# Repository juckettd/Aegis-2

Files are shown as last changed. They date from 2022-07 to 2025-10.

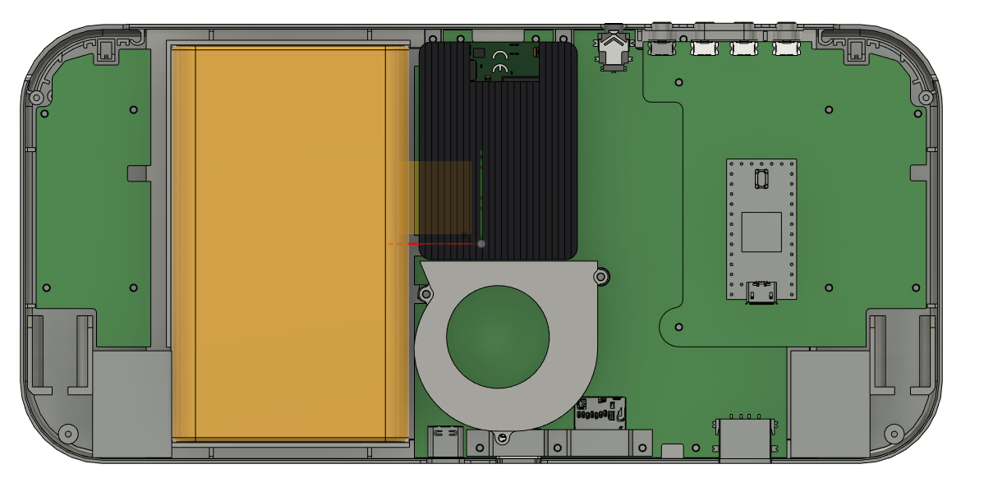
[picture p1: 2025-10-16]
Images/Aegis2_5.PNG

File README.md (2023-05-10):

# Aegis-2
The Aegis 2 Handheld with a 7" screen

NOTE: This is still a work in progress.

## Summary

The Aegis 2 is a DIY handheld that uses a 3D printed case with a Raspberry Pi CM4 and 1920x1200 7" screen.

## Building the Handheld

To build the handheld you will need the items listed as required in the Bill of Materials along with the following tools:

Reflow Station or Reflow Oven<br/>
Solding Iron<br/>
Solder Paste<br/>
Tweezers<br/>
Small Philips Screw Driver<br/>
Small Flathead Screw Driver<br/>
Super Glue (preferrably CA glue with Accelerator)

There are items in the Bill of Materials that are listed as optional. These items are not required to get a working device but can be used if desired. At this time I will not provide directions on how to use the optional components so use at your discretion.

### Assembling the Circuit Board

The custom circuit boards are provided as fusion 360 files in this repository. This includes the schematic, board layout, and the gerber files. 

To get the boards printed, a manufacturing facility is required. The website jlcpcb.com was used to print the 3 circuit board prototypes for the design. The larger of the two boards uses 4 layers, and the smaller ones use only 2 layers. It is recommended to also get the stencils with the boards so that applying the solder paste becomes much easier.

Once the boards have been received you will need to assemble the circuitry on the boards. This is done by getting all of the components provided in the bill of materials. Each item has a provided Link to where the item can be acquired along with the price at the time of the assembly of the prototype. After acquiring all of the components, use the stencil to apply solder paste to the circuit boards and then use tweezers to place each component. A reflow oven or reflow station should then be used to melt the solder paste and adhere the components. Lastly, any through hole components were then added on the using a soldering iron. 

Note: The teensy that is soldered to the board using the through holes. However, there are 4 pads that are located near the USB connector of the Teensy on the custom circuit board. They are the VBUS, D+, D-, and GND connections. I included the VBUS and GND connections as backups but they are not needed as the power and ground comes from the pins. But the D+, D- connections need to be connected to the teensy. On the underside of the teensy there are 4 pads that are in about the same location, a wire or some other form of connection is needed to connect the D+ from the teensy to the D+ on the custom circuit board, do the same with the D- connection.

While anyone who has experience with circuit boards will have their own method for assembling these boards I used the following steps and it is what I recommend for anyone without experience and a reflow oven (but a reflow station is required):
1. Using the stencil, put solder paste on the larger of the two boards on the side with a majority of the components
2. Place all of the surface mount components on that side of the board
3. Use a reflow station and heat the underside of the board until the solder paste on the top side melts to adhere the components. A tool to prop up the PCB comes in handy here. In my opinion this part is essential as some of the components are plastic and the hot air coming out of a reflow station can melt them.
4. Use a soldering iron to clean up an connections that didn't connect completely (You can watch youtube videos on how to do this, just search for solding iron and surface mount components)
5. Flip the board over and redo steps 1-4 for the underside of the board. Since these components are larger I just used the a soldering iron for all of the components, but the same procedure with the reflow station can be used. Just be careful with the hot air hitting components you have already put down, as they can fall off if the solder paste melts again.
6. Perform 1-5 for the second board and the few surface mount components that are on that board
7. Add all of the through hole items to both boards with a soldering iron (again youtube is your friend)

### Install Teensy Code

Before (or after) the circuit board has been assembled the teensy code needs to be pushed to the teensy. The teensy code is provided in the repo and you will need to follow the instructions on the teensy website for pushing code. Make sure that you set the board type to "XInput" otherwise it won't be seen as a XBox 360 Controller.

### 3D Printed Case

The files provided here for the case. They are printed in sections so that a printer with a standard bed size of 220mm x 220mm can be used print the case. Once they are printed they will have to be cleaned up and then glued together. Depending on which angle you choose to print the parts the cleanup step could be more or less cumbersome for the remove of support and getting good glue joints. I choose to print everything with flat surfaces on the bed to keep the post processing steps as easy as possible.

Once everything is glued together then no post processing on the outside is technically required to assemble the device. However, I chose to use filler, sand paper, and paint to get a really clean looking finish. The level of detail you desire on your handheld will be up to you based on how much effort you want to devote. Refer to youtube for how to sand and paint a 3D printed piece. However, try to keep the inside of the device as paint free as possible as the internal structure is already at the correct dimensions for the internal components.

I would also sand down the holes where the buttons will be located as they will to be rough from the 3D printing process. This can cause the buttons to stick. I would also check the shoulder buttons to make sure there is not any friction preventing them from moving properly. If there is then sand down the appropriate areas.

### Assembly

Once the case and the PCB have been built and are ready to go the handheld can be assembled.

TODO: Assembly Instructions

## Software

The Raspberry PI OS Buster version or Retropie both work. To get Bullseye working we need a new video driver that is not available yet. I've made a temporary one and will provide it here when I test it out.

The Config files provided that setup the device will install a monitor program that looks for the button presses for the power/reset/volume/misc. And like the previous handheld I built it will also eventually provide an overlay that will show battery/wifi status along with volume/brightness. However, the overlay does not work yet so that part of the code is commented out. But the monitor script does work for the buttons.

### /boot/config.txt

Regardless of which CM4 you use and which method is used to load the OS, you will need to add the following lines to the /boot/config.txt file. These are also listed in the /Config/boot/config.txt file in this repository:

dtoverlay=dwc2,dr_mode=host<br/>
h264_freq=333

The lines above will optimize the graphics for Moonlight (if you choose to use it to stream PC games) and will enable USB 2.0 on the device to get the Teensy and external USB ports working.

### First Boot

TODO

### System Setup

TODO

## Pictures/Videos

TODO

## Credits

Safe shutdown script
https://github.com/crcerror/ES-generic-shutdown/blob/master/multi_switch.sh

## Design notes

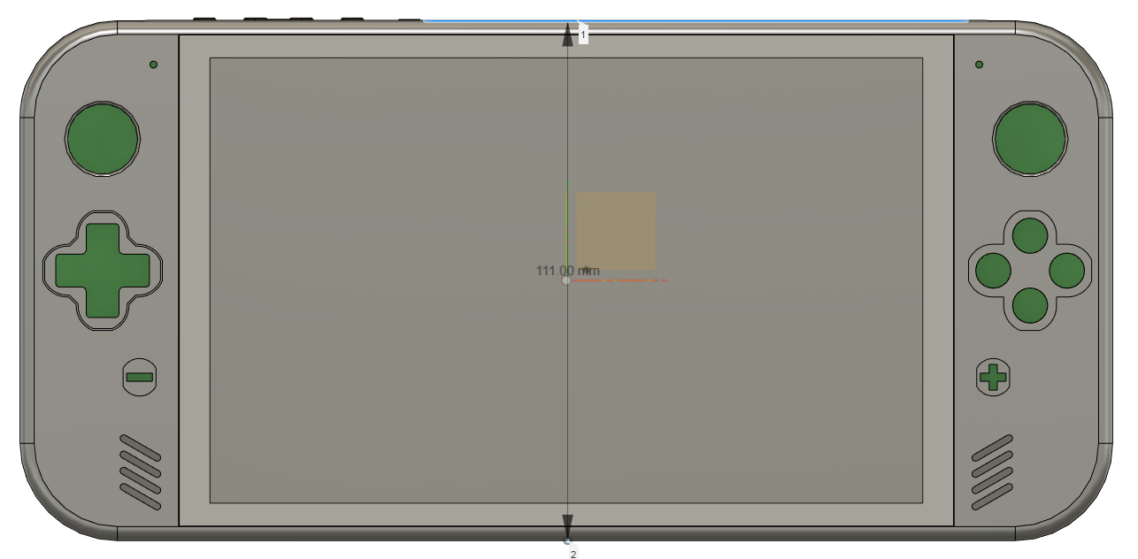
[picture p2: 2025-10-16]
Images/Aegis2_2.png

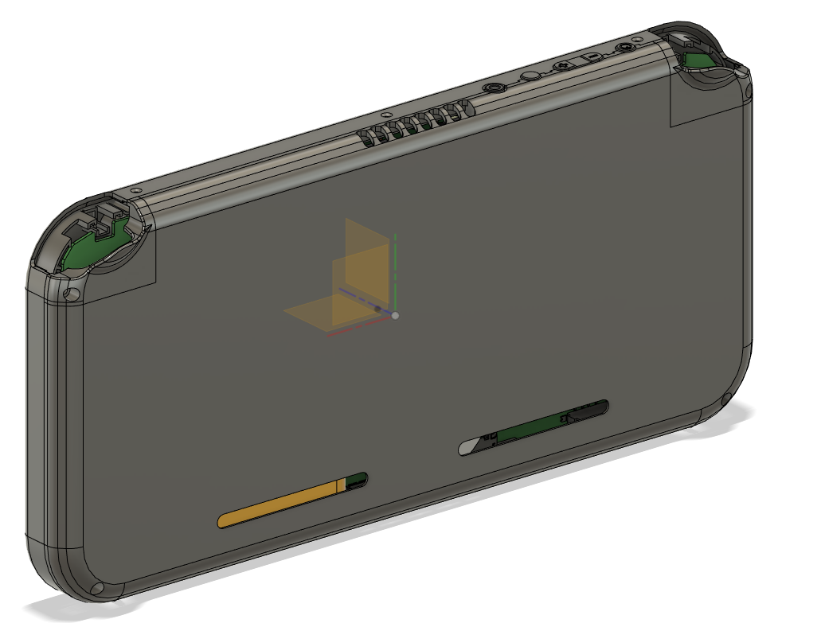
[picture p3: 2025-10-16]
Images/Aegis2_4.PNG

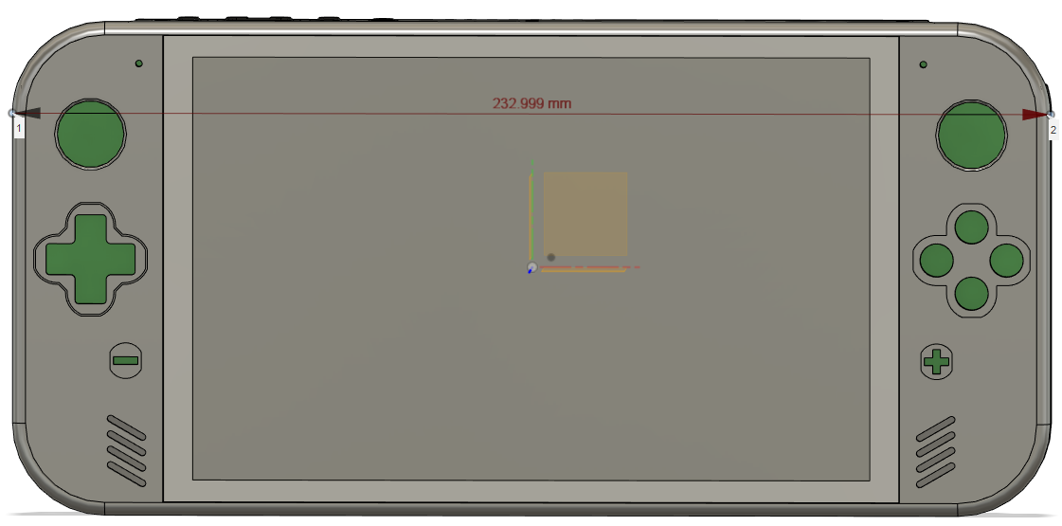
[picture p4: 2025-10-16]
Images/Aegis2.png

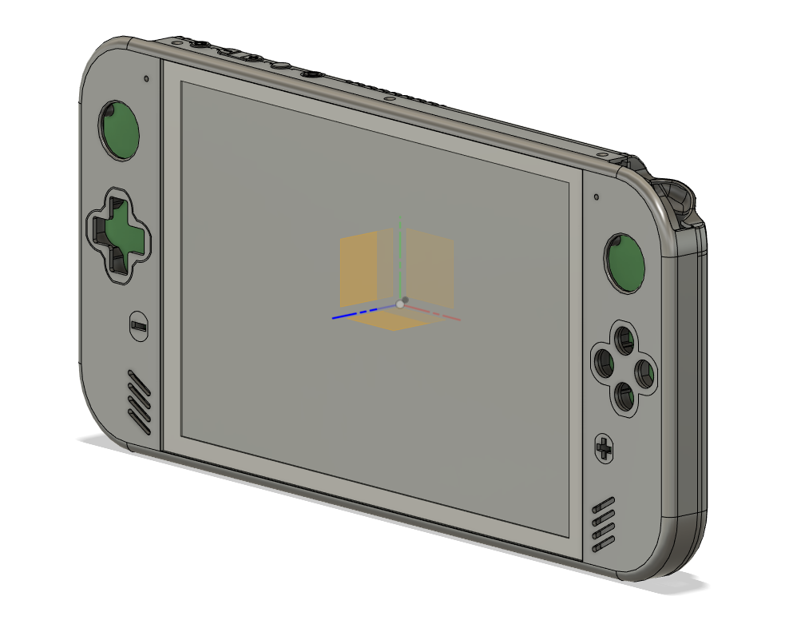
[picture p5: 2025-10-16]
Images/Aegis2_3.PNG

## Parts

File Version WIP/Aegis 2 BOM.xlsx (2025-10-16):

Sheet: Main Board
Item | Component | Qty | Price | Total | Link
Power Items
Battery Charging IC | BAT_CHR | 1 | $4.54 | $4.54 | https://www.digikey.com/product-detail/en/texas-instruments/BQ25895RTWT/296-41132-1-ND/5218172
5V Boost IC | 5V_REG | 1 | $3.04 | $3.04 | https://www.digikey.com/en/products/detail/texas-instruments/TPS61030PWPR/550685
3.3V Buck/Boost IC | 3.3V_REG | 1 | $2.43 | $2.43 | https://www.digikey.com/en/products/detail/texas-instruments/TPS63001DRCR/1016512
Fuel Gauge | FUELGAUGE | 1 | $3.37 | $3.37 | https://www.digikey.com/en/products/detail/analog-devices-inc-maxim-integrated/MAX17055ETB-T/7200799
Battery Connector | BAT_CONN | 1 | $0.50 | $0.50 | https://www.digikey.com/en/products/detail/jst-sales-america-inc/BM03B-ADHKS-GAN-ETB-LF-SN/5272485
Battery Plug | BAT_PLUG | 1 | $0.20 | $0.20 | https://www.digikey.com/en/products/detail/jst-sales-america-inc/ADHR-03V-S/5272192
Battery Wires | BAT_WIRE | 2 | $0.93 | $1.86 | https://www.digikey.com/en/products/detail/jst-sales-america-inc/ASADHSADH26K305/8135688
Power Switch | PWR_SWI | 1 | $0.70 | $0.70 | https://www.digikey.com/en/products/detail/texas-instruments/TPS22976NDPUR/7653221
On/Off Switch | ON/OFF_SWI | 1 | $6.04 | $6.04 | https://www.digikey.com/en/products/detail/analog-devices-inc/LTC2954CTS8-1-TRMPBF/1232657
Audio Items
Headphone Jack | AUDIO_PLUG | 1 | $1.47 | $1.47 | https://www.digikey.com/product-detail/en/adam-tech/ASJ-192-Y-T-R/2057-ASJ-192-Y-T-RCT-ND/9833145
USB Items
USB-C Socket (PWR) | USB_PWR | 2 | $1.90 | $3.80 | https://www.digikey.com/en/products/detail/adam-tech/USB-C31-S-RA-CS1D-BK-T-R/9832218
USB Hub 4-port | USB_HUB | 1 | $3.87 | $3.87 | https://www.digikey.com/en/products/detail/microchip-technology/USB2514BT-I-M2/9923870
USB Current Limit | USB_CURLIM | 1 | $0.46 | $0.46 | https://www.digikey.com/en/products/detail/diodes-incorporated/AP22653W6-7/10481188
24MHz Crystal | CLK_24M | 1 | $0.59 | $0.59 | https://www.digikey.com/en/products/detail/ecs-inc/ECS-240-9-33B-CTP-TR/12349443
USB POE Protection | USB_POE | 1 | $0.80 | $0.80 | https://www.digikey.com/en/products/detail/texas-instruments/TPD4EUSB30DQAR/2503665
HDMI Items
HDMI Socket | HDMI_CONN | 1 | $1.94 | $1.94 | https://www.digikey.com/en/products/detail/cnc-tech/2001-1-2-21-00-BK/4867021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
HDMI Current Limit | HDMI_CURLIM | 1 | $0.40 | $0.40 | https://www.digikey.com/en/products/detail/diodes-incorporated/AP2331W-7/4251553
LCD Items
FPC Connector | FPC_SCREEN | 1 | $3.00 | $3.00 | https://www.mouser.com/ProductDetail/Hirose-Connector/FH35C-31S-0.3SHW99?qs=zPSbg0dgZojH%252BIq5amFHHw%3D%3D
Single Buffer | SD1 | 1 | $0.92 | $0.92 | https://www.digikey.com/en/products/detail/texas-instruments/SN74LVC1G17DBVT/1592019
Fan Items
Fan Connector | FAN_CONN | 1 | $1.38 | $1.38 | https://www.digikey.com/en/products/detail/te-connectivity-amp-connectors/282834-2/1150135
Micro SD Items
Micro SD Socket | MICROSD | 1 | $2.73 | $2.73 | https://www.digikey.com/product-detail/en/molex/5033981892/WM11190CT-ND/5230912
Micro SD Power Switch | MICROSD_SWI | 1 | $4.03 | $4.03 | https://www.digikey.com/en/products/detail/richtek-usa-inc/RT9742GGJ5/5880519
Board Connectors
Mezzanine Connector (RP4) | RPI_PINR1-100, RPI_PINS101-200 | 2 | $1.77 | $3.54 | https://www.digikey.com/en/products/detail/hirose-electric-co-ltd/DF40C-100DS-0-4V-51/1969476
Mezzanine Connector (Board) | BOARD_CONN1 | 1 | $2.12 | $2.12 | https://www.digikey.com/en/products/detail/panasonic-electric-works/AXK5F30347YG/1986662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
Transistors
Transistor NPN | TR1 | 1 | $0.43 | $0.43 | https://www.digikey.com/en/products/detail/diodes-incorporated/DMG2302UKQ-7/9769911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
Diodes
Diode 40V 2A | D1 | 1 | $0.40 | $0.40 | https://www.digikey.com/product-detail/en/diodes-incorporated/SDM2U40CSP-7B/SDM2U40CSP-7BDICT-ND/6013037
Resistors
Res 0.01 (603) | R1 | 1 | $0.94 | $0.94 | https://www.digikey.com/en/products/detail/yageo/PF0603FRE7T0R01Z/2827678
Res 47 (603) | R2 | 1 | $0.11 | $0.11 | https://www.digikey.com/en/products/detail/yageo/RT0603DRE0747RL/1074878
Res 100 (603) | R4 | 1 | $0.18 | $0.18 | https://www.digikey.com/en/products/detail/yageo/RT0603DRD07100RL/1035412
Res 120 (603) | R5 | 1 | $0.10 | $0.10 | https://www.digikey.com/product-detail/en/yageo/RC0603FR-07120RL/311-120HRCT-ND/729867
Res 10K (603) | R3, R6, R7, R8, R9, R10, R11, R12, R13, R14, R15 | 11 | $0.10 | $1.10 | https://www.digikey.com/product-detail/en/yageo/RC0603FR-0710KL/311-10-0KHRCT-ND/729827
Res 12K (603) | R16, R17 | 2 | $0.11 | $0.22 | https://www.digikey.com/en/products/detail/yageo/RT0603DRE0712KL/1074561
Res 15K (603) | R18 | 1 | $0.10 | $0.10 | https://www.digikey.com/en/products/detail/yageo/RC0603FR-0715KL/726953
Res 36K (603) | R19, R20, R21, R22 | 4 | $0.10 | $0.40 | https://www.digikey.com/en/products/detail/yageo/RC0603FR-0736KL/727179
Res 180K (603) | R23 | 1 | $0.10 | $0.10 | https://www.digikey.com/en/products/detail/yageo/RC0603FR-07180KL/726995
Res 1.65M (603) | R24 | 1 | $0.10 | $0.10 | https://www.digikey.com/en/products/detail/yageo/RC0603FR-071M65L/5918265
Res 0 (603) | R25 | 1 | $0.10 | $0.10 | https://www.digikey.com/en/products/detail/yageo/RC0603JR-070RL/726675
Capacitors
Cap 27pF (603) | C1, C2 | 2 | $0.10 | $0.20 | https://www.digikey.com/en/products/detail/samsung-electro-mechanics/CL10C270JB81PNC/3887905
Cap 220pF (603) | C33 | 1 | $0.10 | $0.10 | https://www.digikey.com/en/products/detail/samsung-electro-mechanics/CL10B221KB8NNNC/3886803
Cap 470pF (603) | C34 | 1 | $0.10 | $0.10 | https://www.digikey.com/en/products/detail/yageo/CC0603KPX7R9BB471/691810
Cap 47nF (603) | C3 | 1 | $0.26 | $0.26 | https://www.digikey.com/product-detail/en/murata-electronics/GCJ188R71H473KA12D/490-5854-1-ND/2785840
Cap 0.1uF (603) | C4, C5, C6, C7, C8, C9, C10 | 7 | $0.10 | $0.70 | https://www.digikey.com/en/products/detail/samsung-electro-mechanics/CL10B104KB8NNNL/3894274
Cap 330 nF (603) | C12 | 1 | $0.14 | $0.14 | https://www.digikey.com/en/products/detail/samsung-electro-mechanics/CL10B334KA8VPNC/11487786
Cap 0.47 uF (603) | C13 | 1 | $0.11 | $0.11 | https://www.digikey.com/en/products/detail/tdk-corporation/C1608X7R1C474K080AC/699790
Cap 1uF (603) | C14, C15, C16, C17 | 4 | $0.27 | $1.08 | https://www.digikey.com/product-detail/en/murata-electronics/GCJ188R71E105KA01D/490-14409-1-ND/6606870
Cap 2.2uF (603) | C18 | 1 | $0.13 | $0.13 | https://www.digikey.com/product-detail/en/kemet/C0603C225K4PACTU/399-7886-1-ND/3471609
Cap 4.7uF (603) | C19 | 1 | $0.12 | $0.12 | https://www.digikey.com/en/products/detail/samsung-electro-mechanics/CL10A475KO8NNNC/3889870
Cap 10uF (603) | C23, C24, C25, C26, C27, C28, C29, C30, C31, C32 | 10 | $0.18 | $1.80 | https://www.digikey.com/en/products/detail/murata-electronics/GRM188R61A106KE69D/5026392
Cap 100uF (603) | CT1 | 1 | $0.76 | $0.76 | https://www.digikey.com/en/products/detail/avx-corporation/F980J107MMAAXE/5957626
Cap 220uf (1411) | CT2 | 1 | $0.89 | $0.89 | https://www.digikey.com/en/products/detail/vishay-sprague/T55B227M6R3C0035/5357197
Cap 0.1uf (805 Film) | CF1 | 1 | $0.99 | $0.99 | https://www.digikey.com/en/products/detail/cornell-dubilier-electronics-cde/FCA0805C104M-J2/1924083
Inductors
Ind 2.2uH | L1 | 1 | $1.69 | $1.69 | https://www.digikey.com/product-detail/en/w%C3%BCrth-elektronik/74438357022/732-11201-1-ND/6833660
Ind 6.8uH | L2 | 1 | $0.45 | $0.45 | https://www.digikey.com/product-detail/en/NRS8040T6R8NJGJ/587-2979-1-ND/2666084/?itemSeq=334924146
Ind 2.2uH | L3 | 1 | $0.37 | $0.37 | https://www.digikey.com/en/products/detail/taiyo-yuden/NRS4010T2R2MDGG/2648952
 | Total | Per Unit
Total x1 | $67.90 | $67.90

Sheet: Board 2
Item | Component | Qty | Price | Total | Link
Audio Items
Audio DAC | AUDIO_DAC | 1 | $1.17 | $1.17 | https://www.aliexpress.com/item/33049485687.html?spm=a2g0s.9042311.0.0.1b124c4d3HPSEF
Speaker Amplifier | SPK_AMP | 1 | $2.51 | $2.51 | https://www.digikey.com/en/products/detail/maxim-integrated/MAX98306ETD-T/2708795
Headphone Amplifier | HEAD_AMP | 1 | $0.91 | $0.91 | https://www.digikey.com/en/products/detail/diodes-incorporated/PAM8908JER/4033382
Connectors
Joystick Connector Left | JOYSTICK_L | 1 | $0.68 | $0.68 | https://www.digikey.com/en/products/detail/kyocera-avx/046809605110846/10313186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
Mezzanine Connector (Board) | BOARD_CONN2 | 1 | $2.92 | $2.92 | https://www.digikey.com/en/products/detail/panasonic-electric-works/AXK6F30347YG/1986644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
FPC Connector (Joystick Boards) | CNTRL_BRD_CONN | 1 | $1.75 | $1.75 | https://www.digikey.com/en/products/detail/molex/0527462033/4444652?s=N4IgTCBcDaIAwFYwHYAsA2McDM2QF0BfIA
Motor Connector | SPK_L | 1 | $0.39 | $0.39 | https://www.digikey.com/en/products/detail/molex/0781710002/2424924
Speaker Connector | MTR_L | 1 | $0.39 | $0.39 | https://www.digikey.com/en/products/detail/molex/0781710002/2424924
Tactile Switches
Tactile Switch | BUT_START | 1 | $0.14 | $0.14 | https://www.digikey.com/en/products/detail/mitsumi-electric-company-ltd/R-667834/11591283
Buttons
Buttons | BUT_PWR, BUT_MISC, BUT_VOL_UP, BUT_VOL_DOWN | 4 | $0.72 | $2.88 | https://www.digikey.com/en/products/detail/c-k/KSS331GLFS/417674?s=N4IgTCBcDaINIGUEGZkEYDiAZAYgkAugL5A
Shoulder Button | SHLD_BUT_L | 1 | $1.70 | $1.70 | https://www.ebay.com/itm/354618455099?chn=ps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
LED
Amber LED | LED1 | 1 | $0.55 | $0.55 | https://www.digikey.com/en/products/detail/bivar-inc/SM0805AC/3095524
Buffer Component | BUF1 | 1 | $0.28 | $0.28 | https://www.digikey.com/en/products/detail/diodes-incorporated/74LVC1G07SE-7/2356534
Transistors
Transistor NPN | TR1 | 1 | $0.42 | $0.42 | https://www.digikey.com/en/products/detail/diodes-incorporated/DMG2302UKQ-7/9769911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
Diodes
Diode 40V 2A | D1 | 1 | $0.41 | $0.41 | https://www.digikey.com/product-detail/en/diodes-incorporated/SDM2U40CSP-7B/SDM2U40CSP-7BDICT-ND/6013037
Resistors
Res 0 (603) | R1, R2, R3, R4, R5, R6, R7, R8 | 1 | $0.10 | $0.10 | https://www.digikey.com/en/products/detail/yageo/RC0603JR-070RL/726675
Res 100 (603) | R9, R10 | 2 | $0.18 | $0.36 | https://www.digikey.com/en/products/detail/yageo/RT0603DRD07100RL/1035412
Res 2.2K (603) | R11 | 1 | $0.10 | $0.10 | https://www.digikey.com/en/products/detail/yageo/RC0603FR-072K2L/727016
Res 10K (603) | R12, R13, R14, R15, R16, R17, R18, R19, R20, R21 | 10 | $0.10 | $1.00 | https://www.digikey.com/product-detail/en/yageo/RC0603FR-0710KL/311-10-0KHRCT-ND/729827
Res 100K (603) | R22, R23 | 2 | $0.11 | $0.22 | https://www.digikey.com/en/products/detail/yageo/RT0603DRE07100KL/1074518
Res 220K (603) | R24, R25 | 2 | $0.10 | $0.20 | https://www.digikey.com/en/products/detail/yageo/RC0603FR-07220KL/727062
Capacitors
Cap 0.01uF (603) | C1, C2 | 2 | $0.20 | $0.40 | https://www.digikey.com/en/products/detail/kemet/C0603C103J5REC7411/8572403
Cap 0.1uF (603) | C3, C4, C5, C6, C7, C8 | 6 | $0.10 | $0.60 | https://www.digikey.com/en/products/detail/samsung-electro-mechanics/CL10B104KB8NNNL/3894274
Cap 1uF (603) | C9, C10, C11, C12, C13, C14, C15, C16, C17, C18, C19 | 11 | $0.27 | $2.97 | https://www.digikey.com/product-detail/en/murata-electronics/GCJ188R71E105KA01D/490-14409-1-ND/6606870
Cap 2.2uF (603) | C20 | 1 | $0.13 | $0.13 | https://www.digikey.com/product-detail/en/kemet/C0603C225K4PACTU/399-7886-1-ND/3471609
Cap 10uF (603) | C21, C22, C23, C24, C25 | 5 | $0.18 | $0.90 | https://www.digikey.com/en/products/detail/murata-electronics/GRM188R61A106KE69D/5026392
Cap 47uF (Aluminum Electrolytic) | C26, C27 | 2 | $0.48 | $0.96 | https://www.digikey.com/en/products/detail/panasonic-electronic-components/EEE-HA1C470WR/814162
Ferrite Beads
Ferrite (805) | FB1, FB2 | 2 | $0.10 | $0.20 | https://www.digikey.com/en/products/detail/murata-electronics/BLM18PG471SN1D/1948328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
 | Total | Per Unit
Total x1 | $25.24 | $25.24

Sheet: Board 3
Item | Component | Qty | Price | Total | Link
Connectors
Joystick Connector Left | JOYSTICK_R | 1 | $0.68 | $0.68 | https://www.digikey.com/en/products/detail/kyocera-avx/046809605110846/10313186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
FPC Connector (Joystick Boards) | CNTRL_BRD_CONN | 1 | $1.75 | $1.75 | https://www.digikey.com/en/products/detail/molex/0527462033/4444652?s=N4IgTCBcDaIAwFYwHYAsA2McDM2QF0BfIA
Motor Connector | SPK_R | 1 | $0.39 | $0.39 | https://www.digikey.com/en/products/detail/molex/0781710002/2424924
Speaker Connector | MTR_R | 1 | $0.39 | $0.39 | https://www.digikey.com/en/products/detail/molex/0781710002/2424924
Tactile Switches
Tactile Switch | BUT_SELECT | 1 | $0.14 | $0.14 | https://www.digikey.com/en/products/detail/mitsumi-electric-company-ltd/R-667834/11591283
Buttons
Shoulder Button | SHLD_BUT_R | 1 | $1.70 | $1.70 | https://www.ebay.com/itm/354618455099?chn=ps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
LED
Amber LED | LED1 | 1 | $0.55 | $0.55 | https://www.digikey.com/en/products/detail/bivar-inc/SM0805AC/3095524
Buffer Component | BUF1 | 1 | $0.28 | $0.28 | https://www.digikey.com/en/products/detail/diodes-incorporated/74LVC1G07SE-7/2356534
Transistors
Transistor NPN | TR1 | 1 | $0.42 | $0.42 | https://www.digikey.com/en/products/detail/diodes-incorporated/DMG2302UKQ-7/9769911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
Diodes
Diode 40V 2A | D1 | 1 | $0.41 | $0.41 | https://www.digikey.com/product-detail/en/diodes-incorporated/SDM2U40CSP-7B/SDM2U40CSP-7BDICT-ND/6013037
Resistors
Res 2.2K (603) | R1 | 1 | $0.10 | $0.10 | https://www.digikey.com/en/products/detail/yageo/RC0603FR-072K2L/727016
Res 10K (603) | R2 | 1 | $0.10 | $0.10 | https://www.digikey.com/product-detail/en/yageo/RC0603FR-0710KL/311-10-0KHRCT-ND/729827
Capacitors
Cap 0.1uF (603) | C1, C2 | 2 | $0.10 | $0.20 | https://www.digikey.com/en/products/detail/samsung-electro-mechanics/CL10B104KB8NNNL/3894274
Cap 10uF (603) | C3 | 1 | $0.18 | $0.18 | https://www.digikey.com/en/products/detail/murata-electronics/GRM188R61A106KE69D/5026392
 | Total | Per Unit
Total x1 | $7.29 | $7.29

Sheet: NonPCB Components
Item |  | Qty | Price | Total | Link
Rumble Motors 2pc | RUMBLE | 1 | $7.99 | $7.99 | https://www.amazon.com/gp/product/B07Q71F4L9/ref=ox_sc_act_title_2?smid=A1TBJFOKESMIUW&psc=1
Battery 10000 mAh | BAT | 1 | $9.99 | $9.99 | https://www.aliexpress.us/item/3256802895965671.html
Speakers | SPEAKER | 2 | $3.97 | $7.94 | https://www.digikey.com/en/products/detail/cui-devices/CDS-27204/5355541
Teensy LC | TEENSY | 1 | $12.95 | $12.95 | https://www.sparkfun.com/products/13305
Teensy Header | HEADERS | 1 | $0.57 | $0.57 | https://www.digikey.com/en/products/detail/sullins-connector-solutions/PREC040SABN-RC/2775014
Fan (aliexpress, RFB4505) | FAN | 1 | $9.62 | $9.62 | https://www.aliexpress.us/item/3256803228333750.html?curPageLogUid=DbxWuEx0YQy9
CM4 Heatsink | HEATSINK | 1 | $8.69 | $8.69 | https://www.amazon.com/Dedicated-Aluminum-Heatsink-Raspberry-Compute/dp/B093FSS6XX?hvadid=647248209079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
LED Lens | LENS | 2 | $2.17 | $4.34 | https://www.digikey.com/en/products/detail/bivar-inc/PLPC1-4MM/5721850
Charger Heatsink | HEATSINK2 | 1 | $0.47 | $0.47 | https://www.digikey.com/en/products/detail/assmann-wsw-components/V5618A/3511413
Raspberry PI CM4 | PI_CM4 | 1 | $40.00 | $40.00 | https://www.pishop.us/product/raspberry-pi-compute-module-4-wireless-2gb-lite-cm4102000/
7" Screen | SCREEN | 1 | $24.76 | $24.76 | https://www.aliexpress.us/item/2251832639945508.html
Screen Ribbon Cable (31 Pos, 60mm) | SCREEN_CABLE | 1 | $1.93 | $1.93 | https://www.aliexpress.us/item/3256802654634858.html
Nintendo Switch Lite Rubber Contacts (Full) | CONTACTS | 1 | $1.86 | $1.86 | https://www.aliexpress.us/item/3256802929738782.html
Nintendo Switch Lite Joysticks | JOYSTICKS | 2 | $6.64 | $13.28 | https://www.ebay.com/itm/174968443925
Nintendo Switch Lite Buttons | BUTTONS | 1 | $13.99 | $13.99 | https://www.amazon.com/eXtremeRate-Replacement-Capture-Trigger-Nintendo/dp/B08GXB87W6?th=1
Cables
Joystick Boards Cable | JOYSTICK_CABLE | 1 | $2.68 | $2.68 | https://www.mouser.com/ProductDetail/538-15166-0217
Motor/Speaker Wires | MTR/SPK_WIRES | 4 | $2.30 | $9.20 | https://www.digikey.com/en/products/detail/molex/0369200201/10232988
Hardware
All Screw Set for x1 product |  |  | 1 | $6.90 | https://www.amazon.com/gp/product/B01GE9AK7I/ref=ppx_yo_dt_b_asin_title_o04_s00?ie=UTF8&psc=1
Total |  |  |  | $177.16

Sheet: Tools
Tools | Qty | Price | Total | Link
Double Sided Tape | 1 | $15.99 | $15.99 | https://www.amazon.com/gp/product/B019OQ4YWK/ref=ppx_yo_dt_b_asin_title_o02_s00?ie=UTF8&psc=1
Thermal Adhesive Tape | 1 | $12.99 | $12.99 | https://www.amazon.com/gp/product/B06ZY1JNJV/ref=ppx_yo_dt_b_asin_title_o07_s00?ie=UTF8&psc=1
Kaplan Tape | 1 | $8.99 | $8.99 | https://www.amazon.com/gp/product/B07S1Z877Q/ref=ppx_yo_dt_b_asin_title_o07_s00?ie=UTF8&th=1
Screws | 1 | $6.90 | $6.90 | https://www.amazon.com/gp/product/B01GE9AK7I/ref=ppx_yo_dt_b_asin_image_o03_s00?ie=UTF8&psc=1
Total |  |  | $44.87

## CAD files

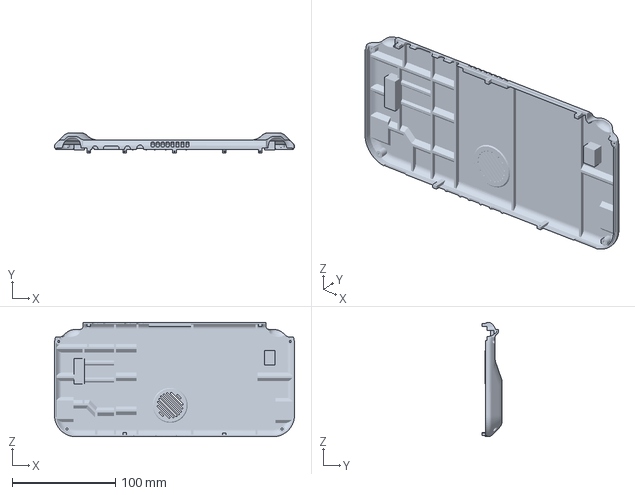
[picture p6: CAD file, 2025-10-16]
Version WIP/CAD/Back With Grips.3mf
233.0 x 19.8 x 111.0 mm

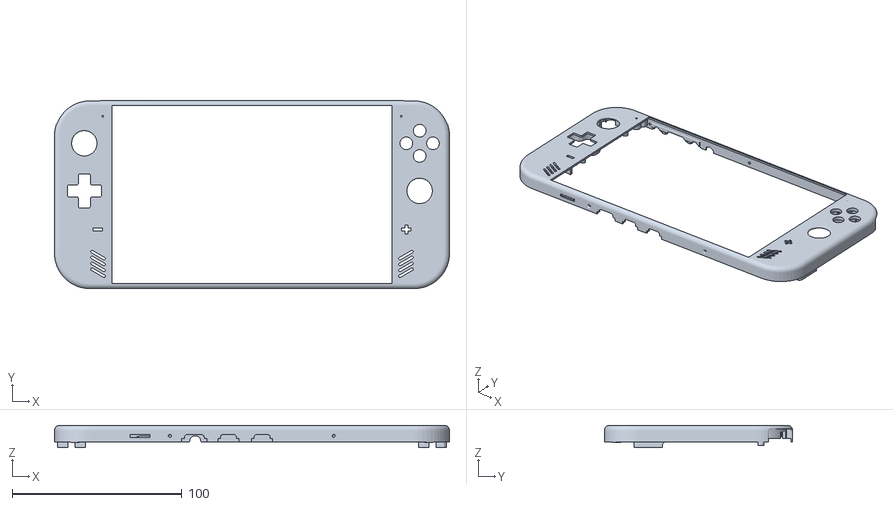
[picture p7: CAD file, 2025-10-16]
Version WIP/CAD/Front Outer Alt.stl
233.0 x 111.0 x 13.2

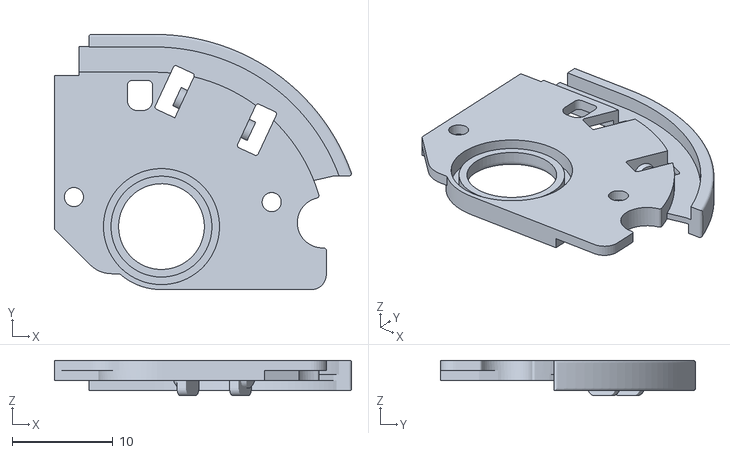
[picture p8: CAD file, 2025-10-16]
Version WIP/CAD/Shoulder Bracket R Alt.stl
29.4 x 25.3 x 3.50

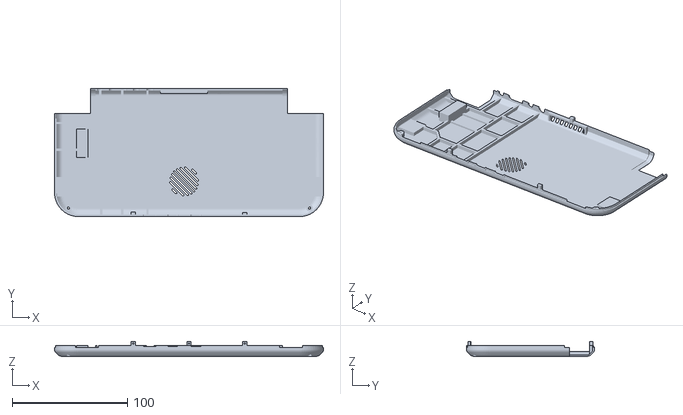
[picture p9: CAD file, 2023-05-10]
Version WIP/CAD/Back Center.stl
233.0 x 111.0 x 12.9

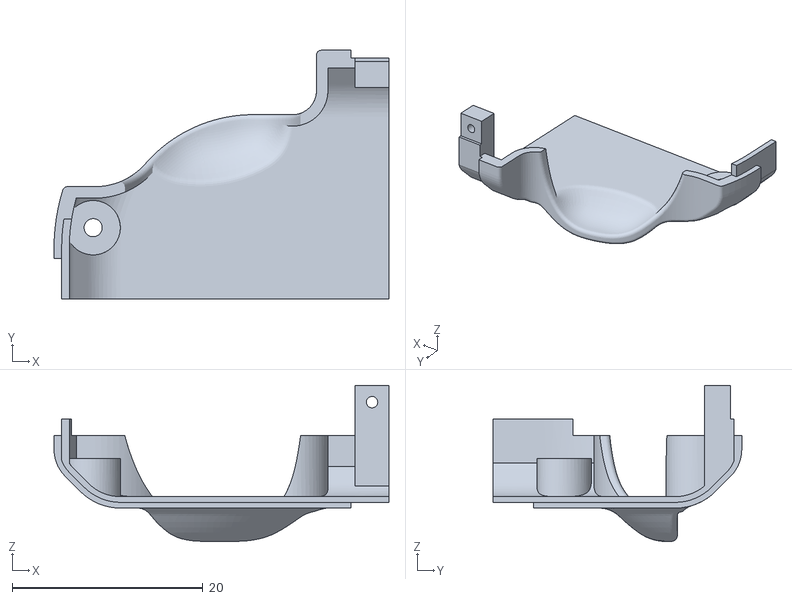
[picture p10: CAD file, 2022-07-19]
Version WIP/CAD/Back Left.stl
35.1 x 26.0 x 16.4

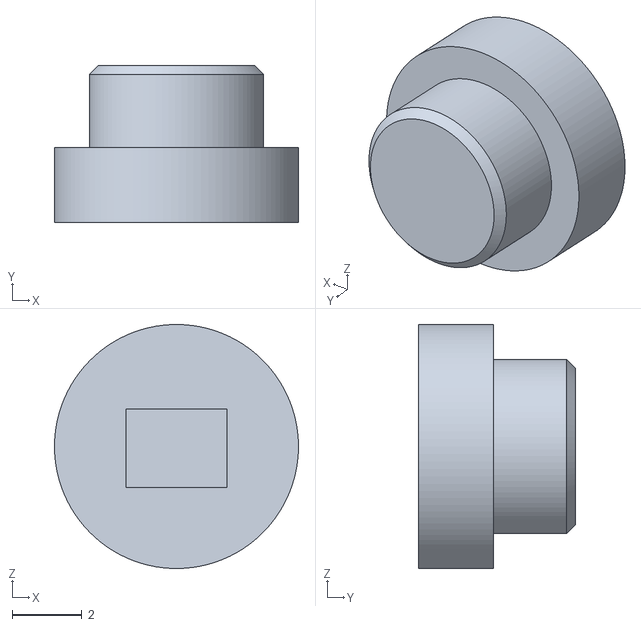
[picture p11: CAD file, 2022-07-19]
Version WIP/CAD/Misc Cap.stl
7.00 x 4.50 x 7.00

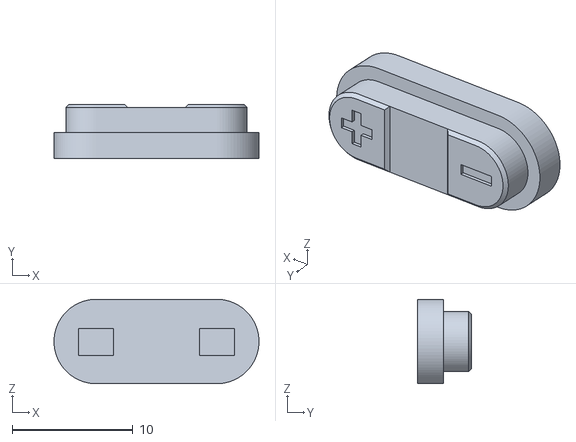
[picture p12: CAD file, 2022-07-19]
Version WIP/CAD/Volume Cap.stl
17.0 x 4.50 x 7.00

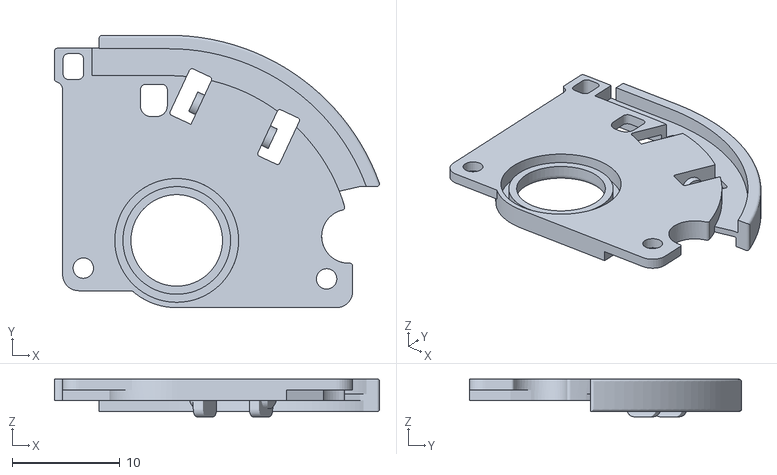
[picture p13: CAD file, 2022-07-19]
Version WIP/CAD/Shoulder Bracket R.stl
30.2 x 25.3 x 3.50

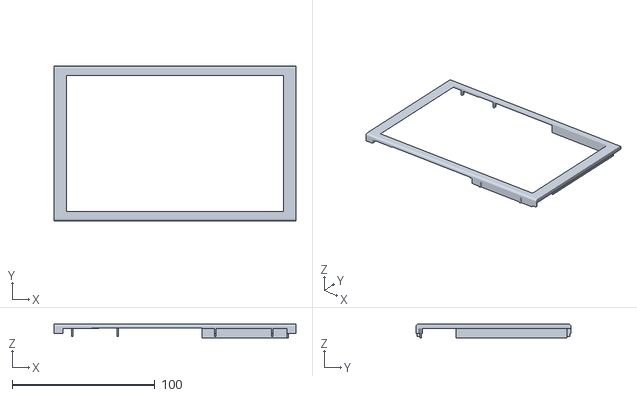
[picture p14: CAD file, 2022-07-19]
Version WIP/CAD/Front Inner.stl
169.4 x 108.5 x 9.70

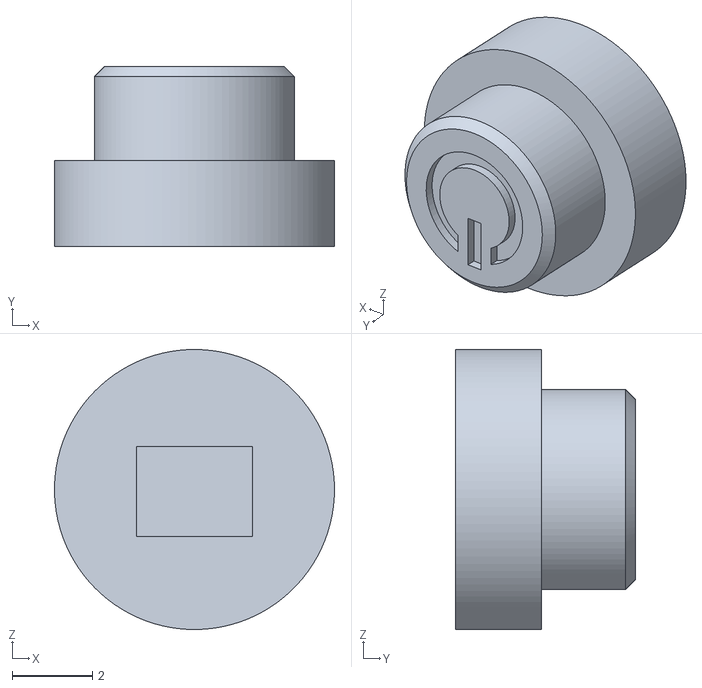
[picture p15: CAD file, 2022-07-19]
Version WIP/CAD/Power Cap.stl
7.00 x 4.50 x 7.00

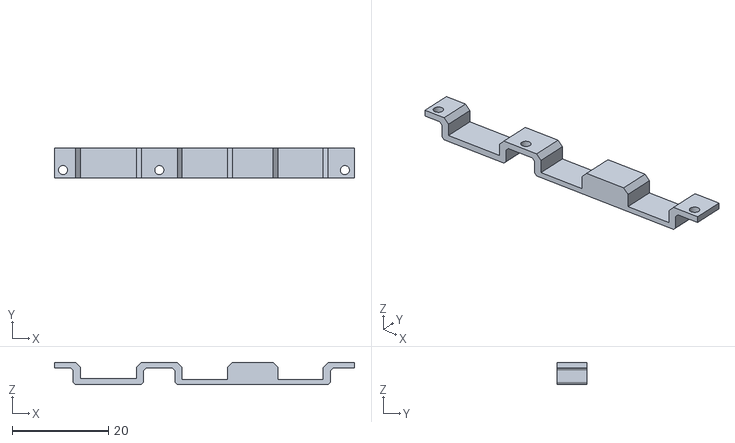
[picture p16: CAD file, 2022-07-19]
Version WIP/CAD/SD Card Slot Bracket.stl
62.5 x 6.28 x 4.60

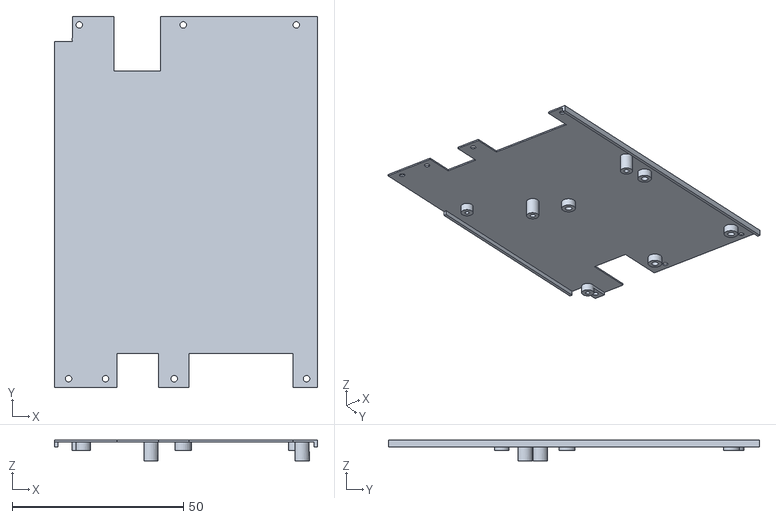
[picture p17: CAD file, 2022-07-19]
Version WIP/CAD/Mounting Bracket.stl
76.8 x 108.4 x 6.10

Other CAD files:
Version WIP/CAD/Front Outer.stl
Version WIP/CAD/Back Right.stl
Version WIP/CAD/Shoulder Bracket L.stl
Version WIP/CAD/Back With Grips.stl

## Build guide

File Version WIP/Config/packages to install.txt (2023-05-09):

dt-blob.bin (screen)
wiringpi (update for CM4)

sudo wget https://datasheets.raspberrypi.com/cmio/dt-blob-disp1-only.bin -O /boot/dt-blob.bin
move dt-blob.bin to /boot/ directory

git clone https://github.com/WiringPi/WiringPi
./build

If using Bullseye then install the Panel Driver into the /lib/modules/[Kernel Version]/kernel/drivers/gpu/drm/panel/

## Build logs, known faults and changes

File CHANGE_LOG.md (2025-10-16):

## Change Log

The change log of the Aegis 2 7" handheld.

Version Number Details:<br/>
x.0.0 - A new version number represents major changes to any and all aspects of the project. A new case and/or circuit board would be required.<br/>
0.x.0 - A new sub-version number represents changes to the circuit board and potentially software but no changes to the case that would require printing<br/>
0.0.x - A new stage represents only software changes where the previous version/sub-version will still work with the updated software. There will not be a separate folder for this update since it is only a software update.<br/>

### Version 0.1.0

Initial Release of the Aegis 2 WIP

### Version 0.2.0

Updated the CAD Files to add a back with grips
Updated the Bill of Materials

### Version 0.3.0

Update a Resistor value from 100 Ohm to 10K Ohm
Update the Teensy code to account for the reversed joystick
Added a new video driver for Raspberry pi OS 64 bit

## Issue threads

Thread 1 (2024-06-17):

about the dpad、screen and so on

Nameless9999, 2024-06-17:
hello~
     1,This  d-pad,abxy and L R  key looks like the Switchlite's ,do I have to buy them to finish the part?The shell looks like a large switchlite by the way, it looks beautiful and more friendly to big-hands players like me.
     2 I  cann't find the 7" screen in the files , which screen should I buy to finish the project?

Yours  , Thanks very much.

Nameless9999, 2024-06-17:
I didn't find the BOM before, now promblem solved. But we still look forward to your final version~ Thank you~~

Closed 2024-06-17.

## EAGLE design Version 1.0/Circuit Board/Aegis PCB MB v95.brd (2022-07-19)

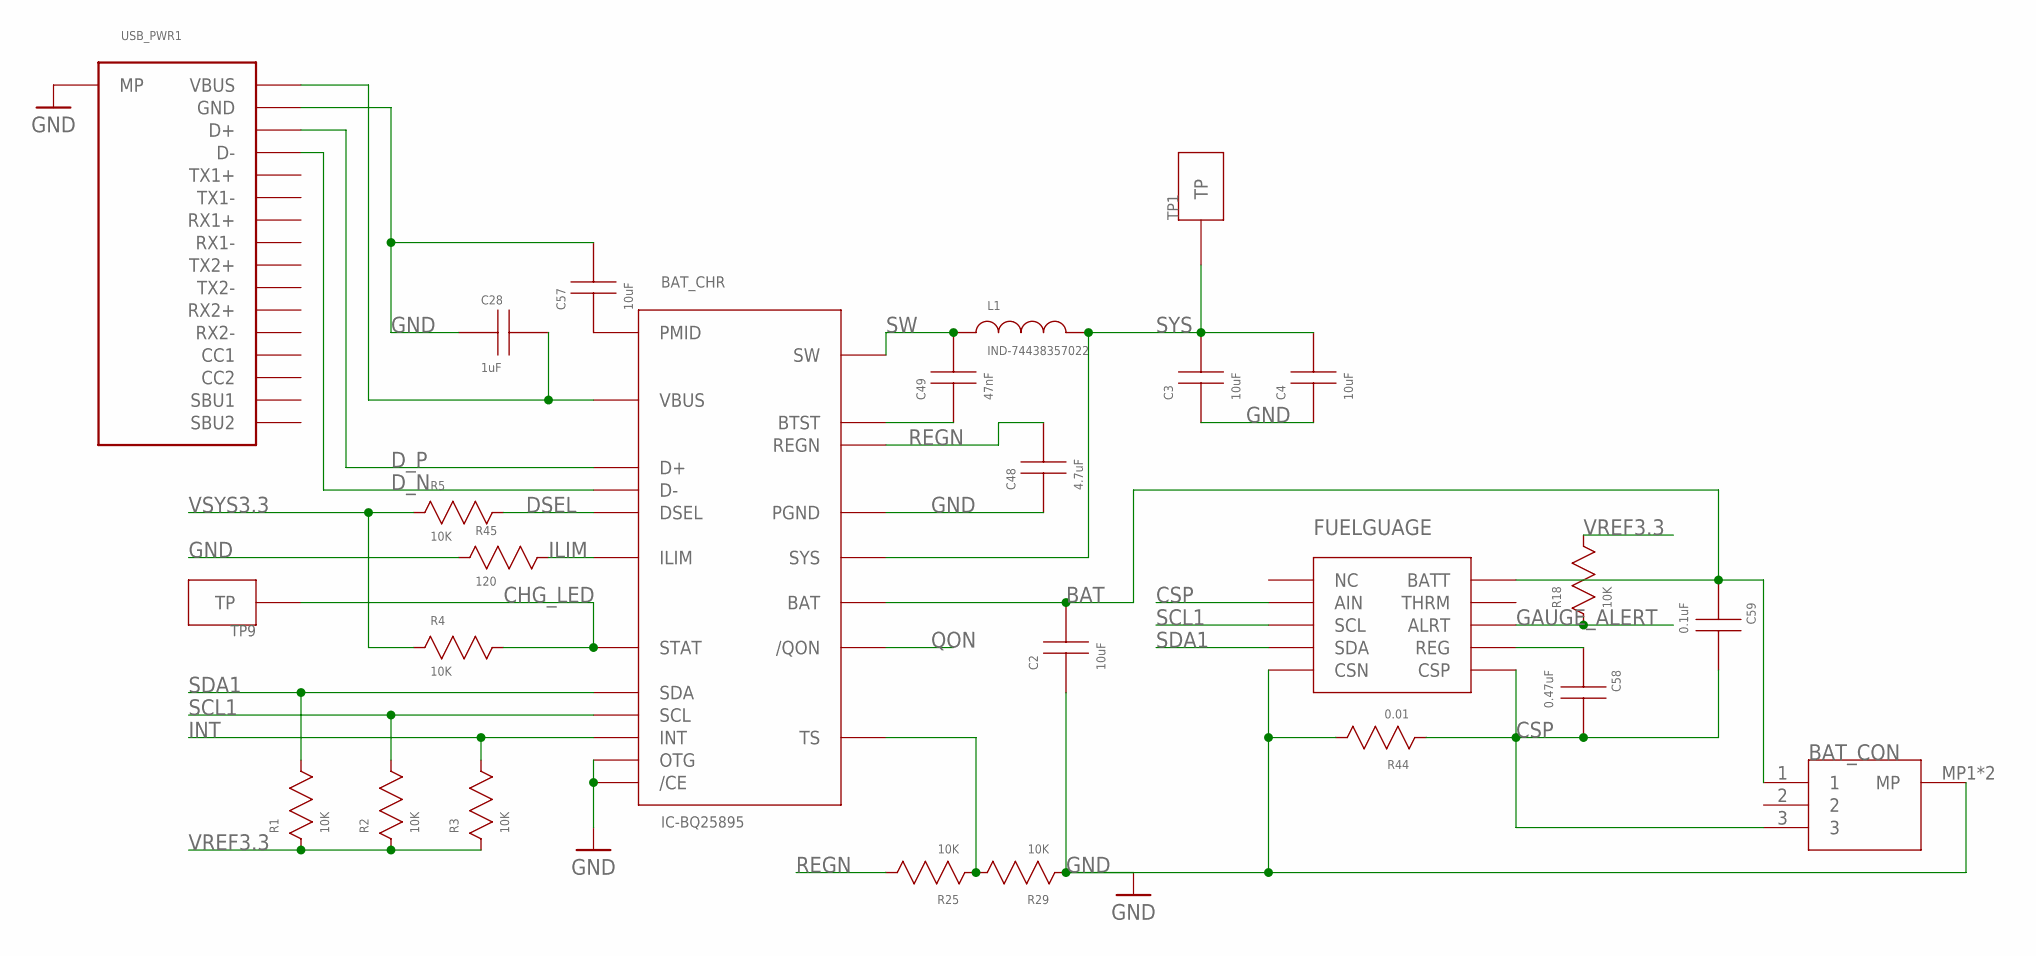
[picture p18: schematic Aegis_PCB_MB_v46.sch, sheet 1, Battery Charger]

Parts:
BAT_CHR: IC-BQ25895
BAT_CON: CONN-AUH03; CONN_AUH03
C2, C3, C4, C57: 10uF; CAP-603
C28: 1uF; CAP-603
C48: 4.7uF; CAP-603
C49: 47nF; CAP-603
C58: 0.47uF; CAP-603
C59: 0.1uF; CAP-603
FUELGUAGE: IC-MAX17055
L1: IND-74438357022
R1, R2, R3, R4, R5, R18, R25, R29: 10K; RES-603
R44: 0.01; RES-603
R45: 120; RES-603
TP1, TP9: TESTPOINT
USB_PWR1: USBC-USB-C31-S-RA-CS1D-BK-T/R

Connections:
BAT: BAT_CHR.BAT1 (BAT), BAT_CHR.BAT2 (BAT), BAT_CON.1, C2.C, C59.A, FUELGUAGE.BATT
CHG_LED: BAT_CHR.STAT, R4.C, TP9.TP; also elsewhere on the board
CSP: BAT_CON.3, C58.C, C59.C, FUELGUAGE.AIN, FUELGUAGE.CSP, FUELGUAGE.EP (CSP), R44.A
DSEL: BAT_CHR.DSEL, R5.C
D_N: BAT_CHR.D-, USB_PWR1.D-, USB_PWR1.D-_2 (D-)
D_P: BAT_CHR.D+, USB_PWR1.D+, USB_PWR1.D+_2 (D+)
GAUGE_ALERT: FUELGUAGE.ALRT, R18.A
GND: BAT_CHR./CE, BAT_CHR.OTG, BAT_CHR.PGND1 (PGND), BAT_CHR.PGND2 (PGND), BAT_CHR.PWRPAD (PGND), BAT_CON.MP1 (MP), BAT_CON.MP2 (MP), C2.A, C3.A, C4.A, C28.A, C48.A, C57.C, FUELGUAGE.CSN, R29.A, R44.C, R45.A, USB_PWR1.GND_1 (GND), USB_PWR1.GND_2 (GND), USB_PWR1.GND_3 (GND), USB_PWR1.GND_4 (GND), USB_PWR1.MP_1 (MP), USB_PWR1.MP_2 (MP), USB_PWR1.MP_3 (MP), USB_PWR1.MP_4 (MP); also elsewhere on the board
ILIM: BAT_CHR.ILIM, R45.C
INT: BAT_CHR.INT, R3.C
unnamed: BAT_CHR.BTST, C49.A
unnamed: BAT_CHR.VBUS, C28.C, USB_PWR1.VBUS_1 (VBUS), USB_PWR1.VBUS_2 (VBUS), USB_PWR1.VBUS_3 (VBUS), USB_PWR1.VBUS_4 (VBUS)
unnamed: BAT_CHR.TS, R25.A, R29.C
unnamed: BAT_CHR.PMID, C57.A
unnamed: C58.A, FUELGUAGE.REG
QON: BAT_CHR./QON
REGN: BAT_CHR.REGN, C48.C, R25.C
SCL1: BAT_CHR.SCL, FUELGUAGE.SCL, R2.C; also elsewhere on the board
SDA1: BAT_CHR.SDA, FUELGUAGE.SDA, R1.C; also elsewhere on the board
SW: BAT_CHR.SW1 (SW), BAT_CHR.SW2 (SW), C49.C, L1.A
SYS: BAT_CHR.SYS1 (SYS), BAT_CHR.SYS2 (SYS), C3.C, C4.C, L1.C, TP1.TP; also elsewhere on the board
VREF3.3: R1.A, R2.A, R3.A, R18.C; also elsewhere on the board
VSYS3.3: R4.A, R5.A; also elsewhere on the board

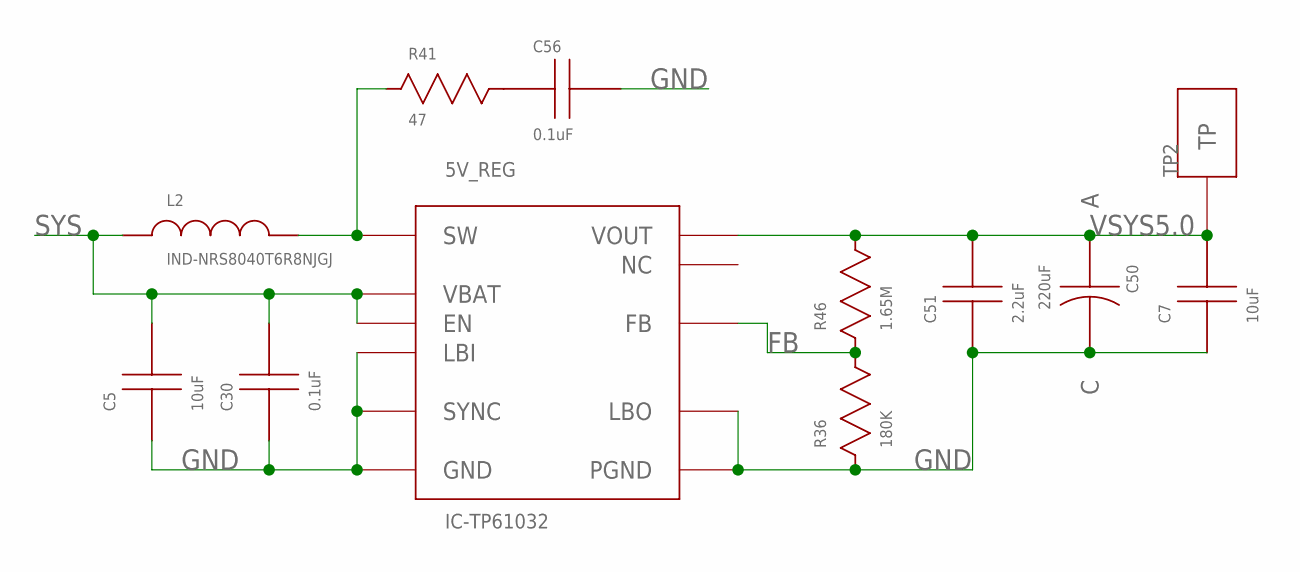
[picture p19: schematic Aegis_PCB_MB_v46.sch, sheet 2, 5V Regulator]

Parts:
5V_REG: IC-TP61032; IC-TPS61032
C5, C7: 10uF; CAP-603
C30, C56: 0.1uF; CAP-603
C50: 220uF; CAP-TAN-1411
C51: 2.2uF; CAP-603
L2: IND-NRS8040T6R8NJGJ
R36: 180K; RES-603
R41: 47; RES-603
R46: 1.65M; RES-603
TP2: TESTPOINT

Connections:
FB: 5V_REG.FB, R36.C, R46.A
GND: 5V_REG.GND, 5V_REG.LBI, 5V_REG.LBO, 5V_REG.PGND1 (PGND), 5V_REG.PGND2 (PGND), 5V_REG.PGND3 (PGND), 5V_REG.PWRPAD (PGND), 5V_REG.SYNC, C5.A, C7.A, C30.A, C50.C, C51.A, C56.C, R36.A; also elsewhere on the board
unnamed: C56.A, R41.C
SNUB: 5V_REG.SW1 (SW), 5V_REG.SW2 (SW), L2.C, R41.A
SYS: 5V_REG.EN, 5V_REG.VBAT, C5.C, C30.C, L2.A; also elsewhere on the board
VSYS5.0: 5V_REG.VOUT1 (VOUT), 5V_REG.VOUT2 (VOUT), 5V_REG.VOUT3 (VOUT), C7.C, C50.A, C51.C, R46.C, TP2.TP; also elsewhere on the board

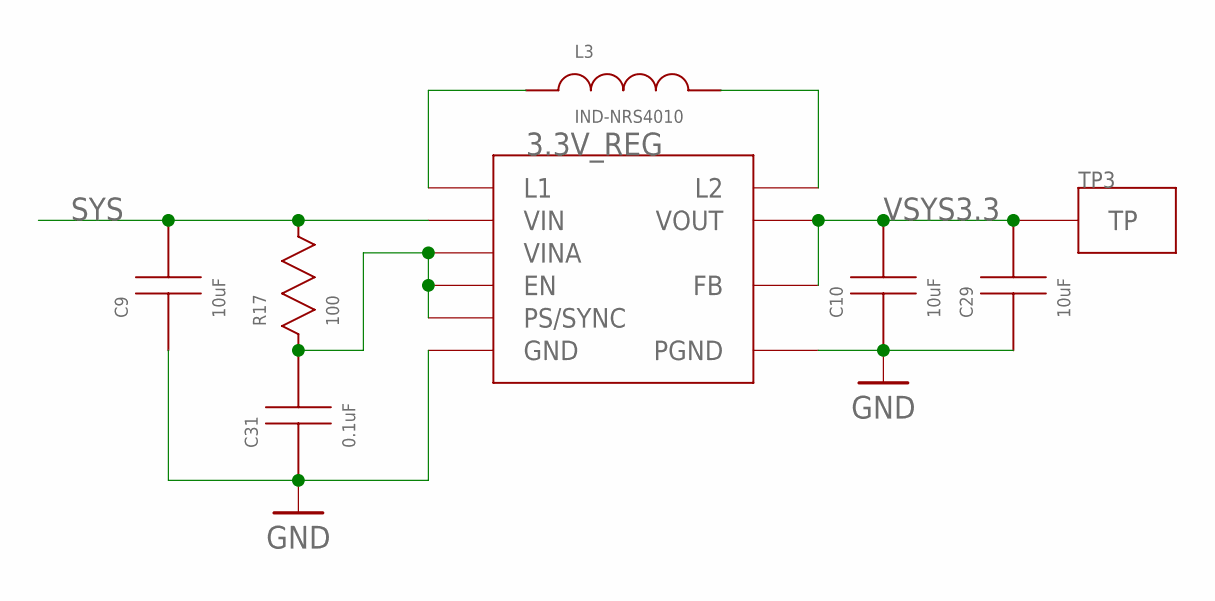
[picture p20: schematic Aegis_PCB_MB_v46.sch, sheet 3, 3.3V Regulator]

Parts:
3.3V_REG: IC-TPS63001DRCR
C9, C10, C29: 10uF; CAP-603
C31: 0.1uF; CAP-603
L3: IND-NRS4010
R17: 100; RES-603
TP3: TESTPOINT

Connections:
GND: 3.3V_REG.GND, 3.3V_REG.PGND, 3.3V_REG.PGND_1 (PGND), 3.3V_REG.PGND_2 (PGND), 3.3V_REG.PGND_3 (PGND), 3.3V_REG.PGND_4 (PGND), 3.3V_REG.PGND_5 (PGND), C9.A, C10.A, C29.A, C31.A; also elsewhere on the board
unnamed: 3.3V_REG.EN, 3.3V_REG.PS/SYNC, 3.3V_REG.VINA, C31.C, R17.A
unnamed: 3.3V_REG.L1, L3.A
unnamed: 3.3V_REG.L2, L3.C
SYS: 3.3V_REG.VIN, C9.C, R17.C; also elsewhere on the board
VSYS3.3: 3.3V_REG.FB, 3.3V_REG.VOUT, C10.C, C29.C, TP3.TP; also elsewhere on the board

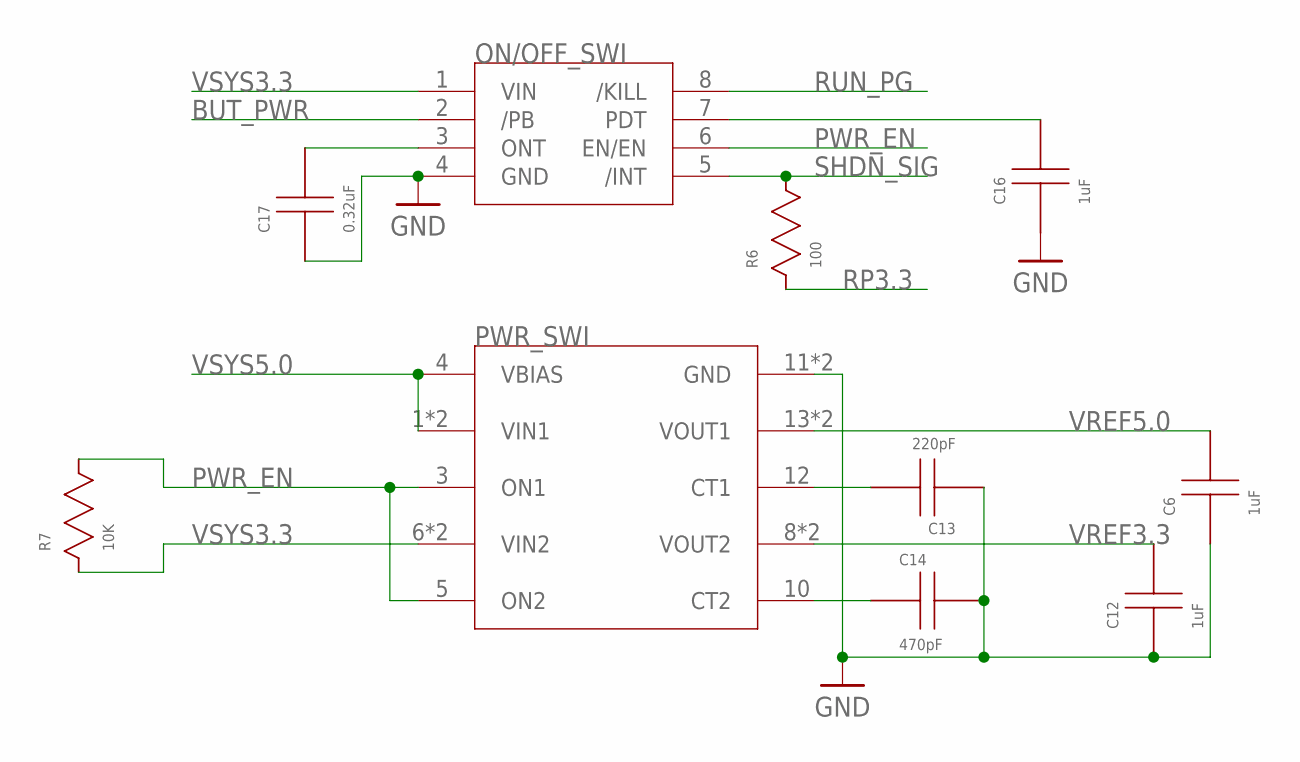
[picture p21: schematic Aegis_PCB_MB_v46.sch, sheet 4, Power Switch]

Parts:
C6, C12, C16: 1uF; CAP-603
C13: 220pF; CAP-603
C14: 470pF; CAP-603
C17: 0.32uF; CAP-603
ON/OFF_SWI: IC-LTC2954
PWR_SWI: IC-TPS22976
R6: 100; RES-603
R7: 10K; RES-603

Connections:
BUT_PWR: ON/OFF_SWI.2 (/PB); also elsewhere on the board
GND: C6.A, C12.A, C13.A, C14.C, C16.A, C17.A, ON/OFF_SWI.4 (GND), PWR_SWI.11 (GND), PWR_SWI.15 (GND); also elsewhere on the board
unnamed: C13.C, PWR_SWI.12 (CT1)
unnamed: C14.A, PWR_SWI.10 (CT2)
unnamed: C16.C, ON/OFF_SWI.7 (PDT)
unnamed: C17.C, ON/OFF_SWI.3 (ONT)
PWR_EN: ON/OFF_SWI.6 (EN/EN), PWR_SWI.3 (ON1), PWR_SWI.5 (ON2), R7.C
RP3.3: R6.A; also elsewhere on the board
RUN_PG: ON/OFF_SWI.8 (/KILL); also elsewhere on the board
SHDN_SIG: ON/OFF_SWI.5 (/INT), R6.C; also elsewhere on the board
VREF3.3: C12.C, PWR_SWI.8 (VOUT2), PWR_SWI.9 (VOUT2); also elsewhere on the board
VREF5.0: C6.C, PWR_SWI.13 (VOUT1), PWR_SWI.14 (VOUT1); also elsewhere on the board
VSYS3.3: ON/OFF_SWI.1 (VIN), PWR_SWI.6 (VIN2), PWR_SWI.7 (VIN2), R7.A; also elsewhere on the board
VSYS5.0: PWR_SWI.1 (VIN1), PWR_SWI.2 (VIN1), PWR_SWI.4 (VBIAS); also elsewhere on the board

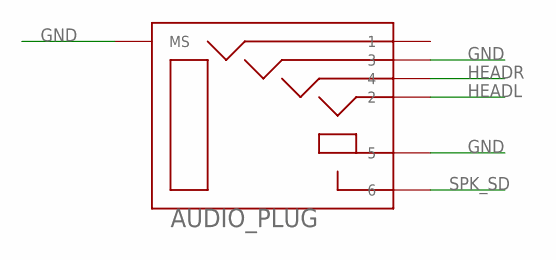
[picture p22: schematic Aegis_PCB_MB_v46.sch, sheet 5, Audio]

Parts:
AUDIO_PLUG: AUDIOPLUG-ASJ-192-Y-TR

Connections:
GND: AUDIO_PLUG.3, AUDIO_PLUG.5, AUDIO_PLUG.MS1 (MS), AUDIO_PLUG.MS2 (MS); also elsewhere on the board
HEADL: AUDIO_PLUG.2; also elsewhere on the board
HEADR: AUDIO_PLUG.4; also elsewhere on the board
SPK_SD: AUDIO_PLUG.6; also elsewhere on the board

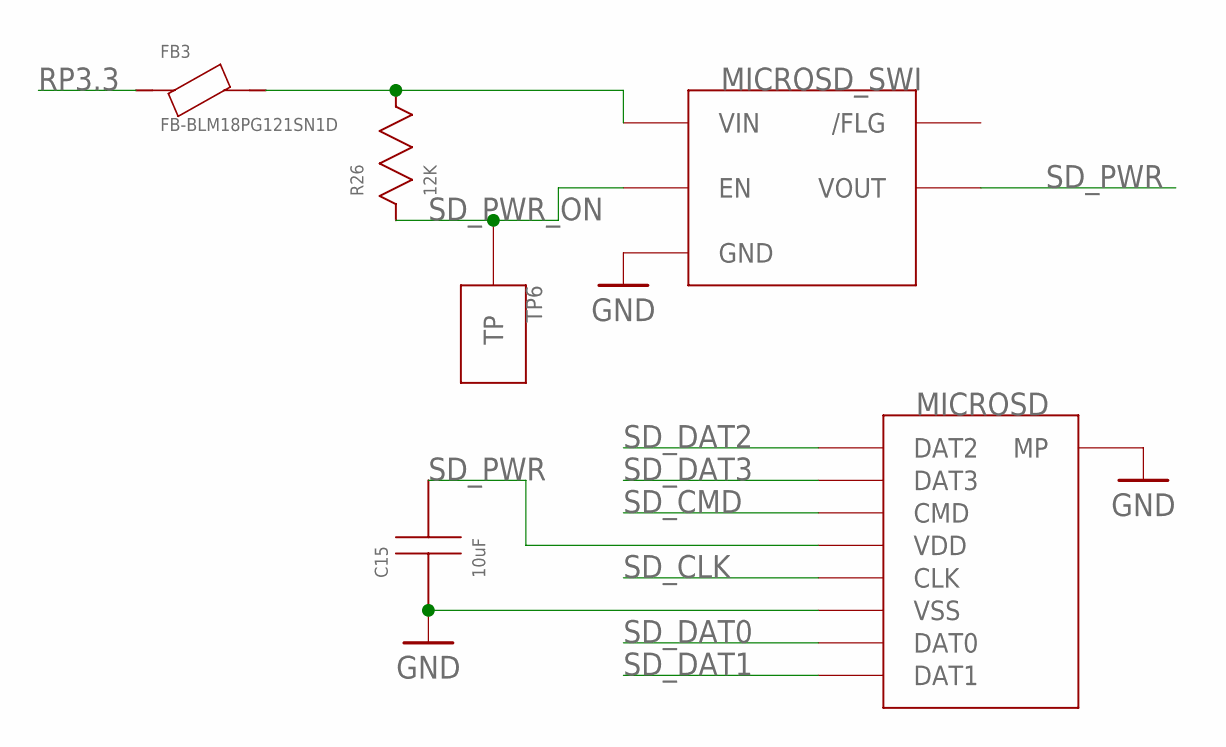
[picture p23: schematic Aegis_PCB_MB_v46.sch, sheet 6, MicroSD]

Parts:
C15: 10uF; CAP-603
FB3: FB-BLM18PG121SN1D
MICROSD: MICROSD-5033981892_SD
MICROSD_SWI: IC-RT9742
R26: 12K; RES-603
TP6: TESTPOINT

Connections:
GND: C15.A, MICROSD.DL (MP), MICROSD.DS (MP), MICROSD.MP_1 (MP), MICROSD.MP_2 (MP), MICROSD.MP_3 (MP), MICROSD.MP_4 (MP), MICROSD.VSS, MICROSD_SWI.GND; also elsewhere on the board
unnamed: FB3.C, MICROSD_SWI.VIN, R26.C
RP3.3: FB3.A; also elsewhere on the board
SD_CLK: MICROSD.CLK; also elsewhere on the board
SD_CMD: MICROSD.CMD; also elsewhere on the board
SD_DAT0: MICROSD.DAT0; also elsewhere on the board
SD_DAT1: MICROSD.DAT1; also elsewhere on the board
SD_DAT2: MICROSD.DAT2; also elsewhere on the board
SD_DAT3: MICROSD.DAT3; also elsewhere on the board
SD_PWR: C15.C, MICROSD.VDD, MICROSD_SWI.VOUT
SD_PWR_ON: MICROSD_SWI.EN, R26.A, TP6.TP; also elsewhere on the board

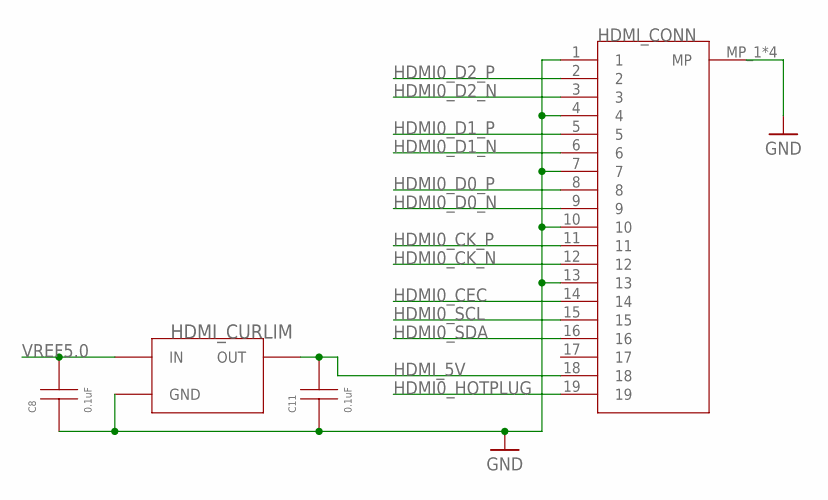
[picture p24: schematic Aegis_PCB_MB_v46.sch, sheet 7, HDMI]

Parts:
C8, C11: 0.1uF; CAP-603
HDMI_CONN: HDMI-2001-1-2-21-00-BK
HDMI_CURLIM: CURLIM-AP2331

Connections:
GND: C8.A, C11.A, HDMI_CONN.1, HDMI_CONN.4, HDMI_CONN.7, HDMI_CONN.10, HDMI_CONN.13, HDMI_CONN.MP_1 (MP), HDMI_CONN.MP_2 (MP), HDMI_CONN.MP_3 (MP), HDMI_CONN.MP_4 (MP), HDMI_CURLIM.GND; also elsewhere on the board
HDMI0_CEC: HDMI_CONN.14; also elsewhere on the board
HDMI0_CK_N: HDMI_CONN.12; also elsewhere on the board
HDMI0_CK_P: HDMI_CONN.11; also elsewhere on the board
HDMI0_D0_N: HDMI_CONN.9; also elsewhere on the board
HDMI0_D0_P: HDMI_CONN.8; also elsewhere on the board
HDMI0_D1_N: HDMI_CONN.6; also elsewhere on the board
HDMI0_D1_P: HDMI_CONN.5; also elsewhere on the board
HDMI0_D2_N: HDMI_CONN.3; also elsewhere on the board
HDMI0_D2_P: HDMI_CONN.2; also elsewhere on the board
HDMI0_HOTPLUG: HDMI_CONN.19; also elsewhere on the board
HDMI0_SCL: HDMI_CONN.15; also elsewhere on the board
HDMI0_SDA: HDMI_CONN.16; also elsewhere on the board
HDMI_5V: C11.C, HDMI_CONN.18, HDMI_CURLIM.OUT
VREF5.0: C8.C, HDMI_CURLIM.IN; also elsewhere on the board

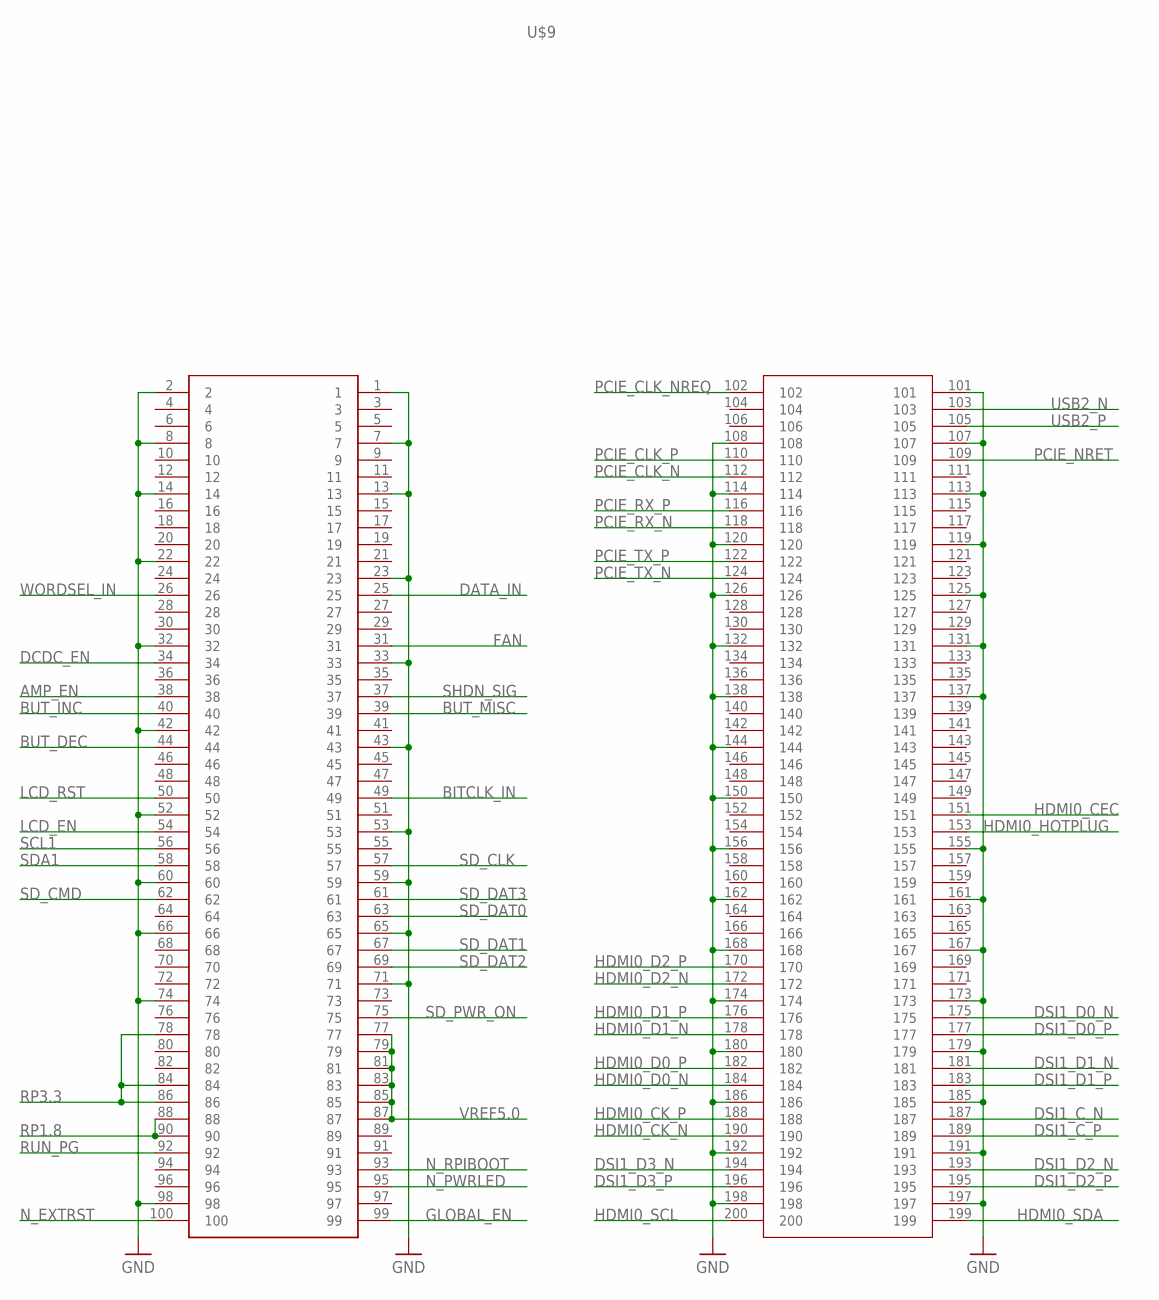
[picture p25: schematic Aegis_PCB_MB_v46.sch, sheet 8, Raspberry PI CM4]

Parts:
U$9: RP_CM4

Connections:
AMP_EN: U$9.38; also elsewhere on the board
BITCLK_IN: U$9.49; also elsewhere on the board
BUT_DEC: U$9.44; also elsewhere on the board
BUT_INC: U$9.40; also elsewhere on the board
BUT_MISC: U$9.39; also elsewhere on the board
DATA_IN: U$9.25; also elsewhere on the board
DCDC_EN: U$9.34; also elsewhere on the board
DSI1_C_N: U$9.187; also elsewhere on the board
DSI1_C_P: U$9.189; also elsewhere on the board
DSI1_D0_N: U$9.175; also elsewhere on the board
DSI1_D0_P: U$9.177; also elsewhere on the board
DSI1_D1_N: U$9.181; also elsewhere on the board
DSI1_D1_P: U$9.183; also elsewhere on the board
DSI1_D2_N: U$9.193; also elsewhere on the board
DSI1_D2_P: U$9.195; also elsewhere on the board
DSI1_D3_N: U$9.194; also elsewhere on the board
DSI1_D3_P: U$9.196; also elsewhere on the board
FAN: U$9.31; also elsewhere on the board
GLOBAL_EN: U$9.99
GND: U$9.1, U$9.2, U$9.7, U$9.8, U$9.13, U$9.14, U$9.22, U$9.23, U$9.32, U$9.33, U$9.42, U$9.43, U$9.52, U$9.53, U$9.59, U$9.60, U$9.65, U$9.66, U$9.71, U$9.74, U$9.98, U$9.101, U$9.107, U$9.108, U$9.113, U$9.114, U$9.119, U$9.120, U$9.125, U$9.126, U$9.131, U$9.132, U$9.137, U$9.138, U$9.144, U$9.150, U$9.155, U$9.156, U$9.161, U$9.162, U$9.167, U$9.168, U$9.173, U$9.174, U$9.179, U$9.180, U$9.185, U$9.186, U$9.191, U$9.192, U$9.197, U$9.198; also elsewhere on the board
HDMI0_CEC: U$9.151; also elsewhere on the board
HDMI0_CK_N: U$9.190; also elsewhere on the board
HDMI0_CK_P: U$9.188; also elsewhere on the board
HDMI0_D0_N: U$9.184; also elsewhere on the board
HDMI0_D0_P: U$9.182; also elsewhere on the board
HDMI0_D1_N: U$9.178; also elsewhere on the board
HDMI0_D1_P: U$9.176; also elsewhere on the board
HDMI0_D2_N: U$9.172; also elsewhere on the board
HDMI0_D2_P: U$9.170; also elsewhere on the board
HDMI0_HOTPLUG: U$9.153; also elsewhere on the board
HDMI0_SCL: U$9.200; also elsewhere on the board
HDMI0_SDA: U$9.199; also elsewhere on the board
LCD_EN: U$9.54; also elsewhere on the board
LCD_RST: U$9.50; also elsewhere on the board
N_EXTRST: U$9.100; also elsewhere on the board
N_PWRLED: U$9.95; also elsewhere on the board
N_RPIBOOT: U$9.93
PCIE_CLK_N: U$9.112
PCIE_CLK_NREQ: U$9.102
PCIE_CLK_P: U$9.110
PCIE_NRET: U$9.109
PCIE_RX_N: U$9.118
PCIE_RX_P: U$9.116
PCIE_TX_N: U$9.124
PCIE_TX_P: U$9.122
RP1.8: U$9.88, U$9.90; also elsewhere on the board
RP3.3: U$9.78, U$9.84, U$9.86; also elsewhere on the board
RUN_PG: U$9.92; also elsewhere on the board
SCL1: U$9.56; also elsewhere on the board
SDA1: U$9.58; also elsewhere on the board
SD_CLK: U$9.57; also elsewhere on the board
SD_CMD: U$9.62; also elsewhere on the board
SD_DAT0: U$9.63; also elsewhere on the board
SD_DAT1: U$9.67; also elsewhere on the board
SD_DAT2: U$9.69; also elsewhere on the board
SD_DAT3: U$9.61; also elsewhere on the board
SD_PWR_ON: U$9.75; also elsewhere on the board
SHDN_SIG: U$9.37; also elsewhere on the board
USB2_N: U$9.103; also elsewhere on the board
USB2_P: U$9.105; also elsewhere on the board
VREF5.0: U$9.77, U$9.79, U$9.81, U$9.83, U$9.85, U$9.87; also elsewhere on the board
WORDSEL_IN: U$9.26; also elsewhere on the board

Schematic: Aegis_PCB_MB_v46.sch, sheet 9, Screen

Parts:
FPC_SCREEN: CONN-FH35C-31S-0.3SHW
R8, R9, R10: 10K; RES-603
SD1: SCHDIODE-SN74LVC1G17

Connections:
DCDC_EN: FPC_SCREEN.30, R8.A; also elsewhere on the board
DSI1_C_N: FPC_SCREEN.15; also elsewhere on the board
DSI1_C_P: FPC_SCREEN.16; also elsewhere on the board
DSI1_D0_N: FPC_SCREEN.12; also elsewhere on the board
DSI1_D0_P: FPC_SCREEN.13; also elsewhere on the board
DSI1_D1_N: FPC_SCREEN.18; also elsewhere on the board
DSI1_D1_P: FPC_SCREEN.19; also elsewhere on the board
DSI1_D2_N: FPC_SCREEN.21; also elsewhere on the board
DSI1_D2_P: FPC_SCREEN.22; also elsewhere on the board
DSI1_D3_N: FPC_SCREEN.9; also elsewhere on the board
DSI1_D3_P: FPC_SCREEN.10; also elsewhere on the board
GND: FPC_SCREEN.5, FPC_SCREEN.8, FPC_SCREEN.11, FPC_SCREEN.14, FPC_SCREEN.17, FPC_SCREEN.20, FPC_SCREEN.23, FPC_SCREEN.28, FPC_SCREEN.29, FPC_SCREEN.M1 (MT), FPC_SCREEN.M2 (MT), R8.C, R9.C, R10.C, SD1.3 (GND); also elsewhere on the board
LCD_EN: FPC_SCREEN.6, R10.A; also elsewhere on the board
LCD_RST: SD1.2 (A); also elsewhere on the board
LCD_RST_ADJ: FPC_SCREEN.24, R9.A, SD1.4 (Y)
RP1.8: FPC_SCREEN.31, SD1.5 (VCC); also elsewhere on the board
RP3.3: FPC_SCREEN.26, FPC_SCREEN.27; also elsewhere on the board
VREF3.3: FPC_SCREEN.1, FPC_SCREEN.2, FPC_SCREEN.3, FPC_SCREEN.4; also elsewhere on the board

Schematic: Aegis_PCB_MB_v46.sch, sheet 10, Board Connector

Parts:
BOARD_CONN1: CONN-AXK5F30347YG

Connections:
AMP_EN: BOARD_CONN1.10; also elsewhere on the board
BITCLK_IN: BOARD_CONN1.2; also elsewhere on the board
BUT_DEC: BOARD_CONN1.5; also elsewhere on the board
BUT_INC: BOARD_CONN1.6; also elsewhere on the board
BUT_MISC: BOARD_CONN1.7; also elsewhere on the board
BUT_PWR: BOARD_CONN1.8; also elsewhere on the board
CHG_LED: BOARD_CONN1.9; also elsewhere on the board
DATA_IN: BOARD_CONN1.4; also elsewhere on the board
GND: BOARD_CONN1.18, BOARD_CONN1.19, BOARD_CONN1.20, BOARD_CONN1.21, BOARD_CONN1.22, BOARD_CONN1.23, BOARD_CONN1.24, BOARD_CONN1.25; also elsewhere on the board
HEADL: BOARD_CONN1.12; also elsewhere on the board
HEADR: BOARD_CONN1.13; also elsewhere on the board
N_PWRLED: BOARD_CONN1.1; also elsewhere on the board
SPK_SD: BOARD_CONN1.11; also elsewhere on the board
TD_N: BOARD_CONN1.15; also elsewhere on the board
TD_P: BOARD_CONN1.14; also elsewhere on the board
VBUS1: BOARD_CONN1.16, BOARD_CONN1.17; also elsewhere on the board
VREF3.3: BOARD_CONN1.26, BOARD_CONN1.27, BOARD_CONN1.28, BOARD_CONN1.29; also elsewhere on the board
VSYS3.3: BOARD_CONN1.30; also elsewhere on the board
WORDSEL_IN: BOARD_CONN1.3; also elsewhere on the board

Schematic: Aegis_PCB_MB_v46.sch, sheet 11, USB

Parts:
C1: 100uF; CAP-603
C19, C20, C21: 10uF; CAP-603
C43: 0.1uF; CAP-603
C52, C53: 27pF; CAP-603
CLK_24M: CLK-ECS-240
R27: 12K; RES-603
R28: 15K; RES-603
R30, R31, R32, R33: 36K; RES-603
TP14: TESTPOINT
USB_CURLIM: CURLIM-AP22653W6
USB_HUB: USBPORT-USB2514BT-I/M2
USB_POE: POE_PROT-TPD4EUSB30DQAR
USB_PWR2: USBC-USB-C31-S-RA-CS1D-BK-T/R

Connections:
D1_N: USB_HUB.3, USB_POE.D1-, USB_PWR2.D-, USB_PWR2.D-_2 (D-)
D1_P: USB_HUB.4, USB_POE.D1+, USB_PWR2.D+, USB_PWR2.D+_2 (D+)
GND: C1.A, C19.A, C20.A, C21.A, C43.A, C52.A, C53.A, CLK_24M.GND_1 (GND), CLK_24M.GND_2 (GND), R27.C, R28.A, R30.C, R31.C, R32.C, R33.C, USB_CURLIM.GND, USB_HUB.37, USB_POE.GND_1 (GND), USB_POE.GND_2 (GND), USB_PWR2.GND_1 (GND), USB_PWR2.GND_2 (GND), USB_PWR2.GND_3 (GND), USB_PWR2.GND_4 (GND), USB_PWR2.MP_1 (MP), USB_PWR2.MP_2 (MP), USB_PWR2.MP_3 (MP), USB_PWR2.MP_4 (MP); also elsewhere on the board
unnamed: R32.A, USB_HUB.28
unnamed: R28.C, USB_CURLIM.ILIM
unnamed: R31.A, USB_HUB.22
unnamed: R30.A, USB_HUB.24
unnamed: C53.C, CLK_24M.OUT/IN, USB_HUB.32
unnamed: C52.C, CLK_24M.IN/OUT, USB_HUB.33
unnamed: R33.A, USB_HUB.25
unnamed: R27.A, USB_HUB.35
N_EXTRST: USB_HUB.26; also elsewhere on the board
N_OCS1: USB_CURLIM.NFAULT, USB_HUB.13, USB_HUB.17, USB_HUB.19, USB_HUB.21
PWR1: USB_CURLIM.EN, USB_HUB.12
TD_N: USB_HUB.1, USB_POE.D2-; also elsewhere on the board
TD_P: USB_HUB.2, USB_POE.D2+; also elsewhere on the board
USB2_N: USB_HUB.30; also elsewhere on the board
USB2_P: USB_HUB.31; also elsewhere on the board
VBUS1: C1.C, C21.C, TP14.TP, USB_CURLIM.OUT, USB_PWR2.VBUS_1 (VBUS), USB_PWR2.VBUS_2 (VBUS), USB_PWR2.VBUS_3 (VBUS), USB_PWR2.VBUS_4 (VBUS); also elsewhere on the board
VREF3.3: C19.C, C43.C, USB_HUB.5, USB_HUB.10, USB_HUB.15, USB_HUB.23, USB_HUB.27, USB_HUB.29, USB_HUB.36; also elsewhere on the board
VREF5.0: C20.C, USB_CURLIM.IN; also elsewhere on the board

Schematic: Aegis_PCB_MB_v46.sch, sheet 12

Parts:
C44: 0.1uF; CAP-603
D3: DIODE-X3-WLB1608-2
FAN_CONN: CONN-282834-2
R19: 10K; RES-603
TP16: TESTPOINT
TR3: TRAN-DMG2302UKQ

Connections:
FAN: R19.C, TP16.TP, TR3.G; also elsewhere on the board
GND: C44.A, R19.A, TR3.S; also elsewhere on the board
unnamed: D3.A, FAN_CONN.2, TR3.D
VREF3.3: C44.C, D3.C, FAN_CONN.1; also elsewhere on the board

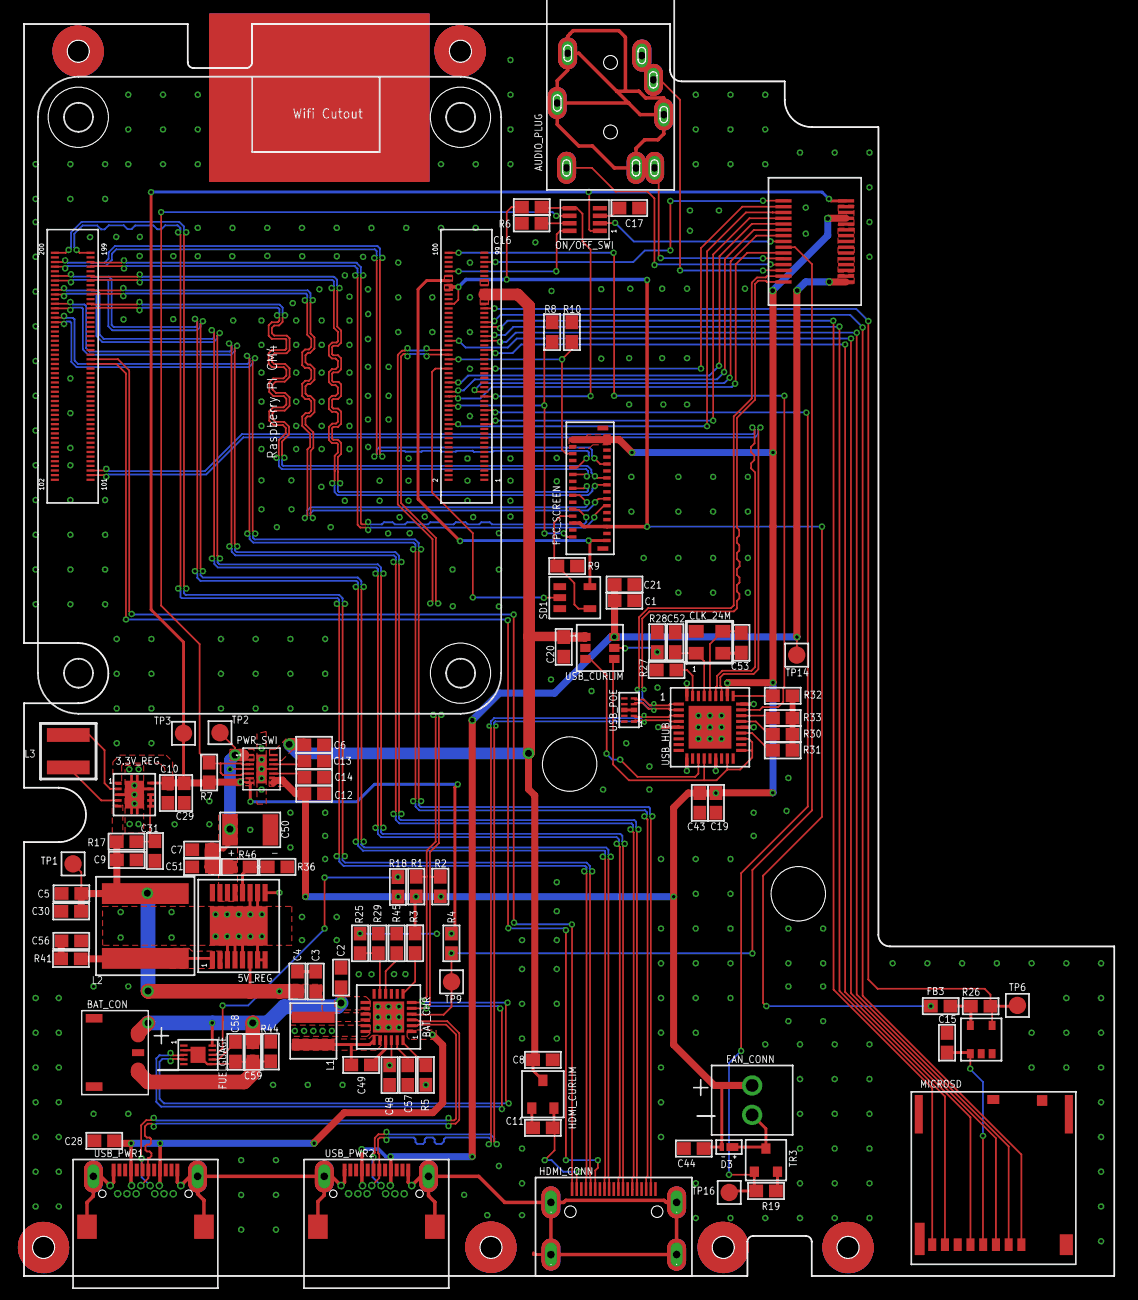
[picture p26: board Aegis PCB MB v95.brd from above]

Board: 4 copper layers, 94.1 x 108.1 mm, 99 parts (0 on the bottom side), 107 nets.

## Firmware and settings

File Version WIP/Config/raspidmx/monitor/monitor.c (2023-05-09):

//-------------------------------------------------------------------------
//
// The MIT License (MIT)
//
// Copyright (c) 2013 Andrew Duncan
//
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
//-------------------------------------------------------------------------

//#define _GNU_SOURCE

#include <assert.h>
#include <ctype.h>
#include <signal.h>
#include <stdbool.h>
#include <stdio.h>
#include <stdlib.h>
#include <strings.h>
#include <unistd.h>
//#include <pigpio.h>
#include <wiringPi.h>
#include <wiringPiI2C.h>
#include <alsa/asoundlib.h>
#include <sys/reboot.h>

#include "backgroundLayer.h"
#include "imageLayer.h"
#include "key.h"
#include "loadpng.h"
#include "bcm_host.h"

#ifndef ICON_BUF
#define ICON_BUF 200
#endif

#ifndef MAX_BUF
#define MAX_BUF 400
#endif

//-------------------------------------------------------------------------

//#define NDEBUG

//-------------------------------------------------------------------------

const char *program = NULL;
char iconpath[ICON_BUF] = "/usr/local/bin/overlay_icons/";
//char iconpath[ICON_BUF];

char env_icons[3][MAX_BUF];
char wifi_icons[6][MAX_BUF];
char bt_icons[2][MAX_BUF];
char bar_icons[3][MAX_BUF];
char critical_battery_icon[MAX_BUF];
char battery_icons[10][MAX_BUF];
char color[] = "white";
char wifi_carrier[] = "/sys/class/net/wlan0/carrier"; // 1 when wifi connected, 0 when disconnected and/or ifdown
char wifi_linkmode[] = "/sys/class/net/wlan0/link_mode"; // 1 when ifup, 0 when ifdown
char bt_devices_dir[] = "/sys/class/bluetooth";
char backlight[] = "/sys/class/backlight/fe700000.dsi.0/brightness";
char env_cmd[] = "vcgencmd get_throttled";
char temp_cmd[] = "vcgencmd measure_temp";

int dpi = 24;
int fan_on_temp = 60;
int battery_index = -1;
int wifi_index = -1;
int bt_index = -1;
int under_voltage = 0;
int freq_capped = 0;
int throttled = 0;
int critical_shutdown = 0;
int percent_levels[9] = {5, 10, 20, 30, 50, 60, 80, 90, 100};
char battery_level[] = "blah";

int pmin = 2;
uint32_t displayNumber = 0;
uint32_t powerButtonTime = 2000000;
uint32_t volbriBarTime = 3000000;
uint32_t miscButtonTime = 2000000;
uint32_t incdecButtonTime = 500000;
uint32_t criticalShutdownTime = 60000000;
uint32_t fanMinTime = 60000000;

int battery_charger_handle = 0;
int fuel_gauge_handle = 0;

volatile int display_brightness = 0;
volatile int display_volume = 0;
volatile uint32_t display_tick = 0;

volatile int decrease_pressed = 0;
volatile uint32_t decrease_tick = 0;
volatile int increase_pressed = 0;
volatile uint32_t increase_tick = 0;
volatile int misc_pressed = 0;
volatile int misc_alt = 0;
volatile uint32_t misc_tick = 0;
volatile int power_pressed = 0;
volatile uint32_t power_tick = 0;
volatile uint32_t critical_shutdown_tick = 0;

IMAGE_LAYER_T critical_battery_img;
IMAGE_LAYER_T battery_img[10];
IMAGE_LAYER_T wifi_img[6];
IMAGE_LAYER_T bluetooth_img[2];
IMAGE_LAYER_T under_voltage_img;
IMAGE_LAYER_T freq_capped_img;
IMAGE_LAYER_T throttled_img;
IMAGE_LAYER_T volume_bar_img;
IMAGE_LAYER_T brightness_bar_img;
IMAGE_LAYER_T dot_img;

DISPMANX_DISPLAY_HANDLE_T display;
DISPMANX_UPDATE_HANDLE_T update;
DISPMANX_MODEINFO_T info;

snd_mixer_t* handle = NULL;
snd_mixer_elem_t* elem = NULL;

//-------------------------------------------------------------------------

volatile bool run = true;
volatile bool shutdown = false;
volatile bool restart = false;

void gpioISR7();
void gpioISR8();
void gpioISR9();
void gpioISR10();
//void gpioISR(int gpio, int level, uint32_t tick);

//-------------------------------------------------------------------------

static void
signalHandler(
	int signalNumber)
{
	switch (signalNumber)
	{
		case SIGINT:
		case SIGTERM:

			run = false;
			break;
	};
}

//-------------------------------------------------------------------------

void setupDisplay()
{
	if (signal(SIGINT, signalHandler) == SIG_ERR)
	{
		perror("installing SIGINT signal handler");
		exit(EXIT_FAILURE);
	}

	//---------------------------------------------------------------------

	if (signal(SIGTERM, signalHandler) == SIG_ERR)
	{
		perror("installing SIGTERM signal handler");
		exit(EXIT_FAILURE);
	}

	//---------------------------------------------------------------------

	bcm_host_init();

	//---------------------------------------------------------------------

	//display = vc_dispmanx_display_open(displayNumber);
	//assert(display != 0);

	//---------------------------------------------------------------------

	//int result = vc_dispmanx_display_get_info(display, &info);
	//assert(result == 0);
}

void setupFiles()
{
	char levels[9][MAX_BUF] = {"alert_red", "alert", "20", "30", "50", "60", "80", "90", "full" };

	//getcwd(iconpath, ICON_BUF);
	//strcat(iconpath, "/overlay_icons/");

	for (int i = 0; i < 9; i++)
		sprintf(battery_icons[i], "%s%s%s%s%s%s%d%s", iconpath, "twotone_battery_", levels[i], "_", color, "_",  dpi, "dp.png");
	sprintf(battery_icons[9], "%s%s%s%s%d%s", iconpath, "twotone_battery_charging_", color, "_",  dpi, "dp.png");

	sprintf(env_icons[0], "%s%s%d%s", iconpath, "flash_", dpi, "dp.png");
	sprintf(env_icons[1], "%s%s%d%s", iconpath, "thermometer_", dpi, "dp.png");
	sprintf(env_icons[2], "%s%s%d%s", iconpath, "thermometer-lines_", dpi, "dp.png");

	sprintf(wifi_icons[0], "%s%s%s%s%d%s", iconpath, "twotone_signal_wifi_off_", color, "_", dpi, "dp.png");
	sprintf(wifi_icons[1], "%s%s%s%s%d%s", iconpath, "twotone_signal_wifi_0_bar_", color, "_", dpi, "dp.png");
	sprintf(wifi_icons[2], "%s%s%s%s%d%s", iconpath, "twotone_signal_wifi_1_bar_", color, "_", dpi, "dp.png");
	sprintf(wifi_icons[3], "%s%s%s%s%d%s", iconpath, "twotone_signal_wifi_2_bar_", color, "_", dpi, "dp.png");
	sprintf(wifi_icons[4], "%s%s%s%s%d%s", iconpath, "twotone_signal_wifi_3_bar_", color, "_", dpi, "dp.png");
	sprintf(wifi_icons[5], "%s%s%s%s%d%s", iconpath, "twotone_signal_wifi_4_bar_", color, "_", dpi, "dp.png");

	sprintf(bt_icons[0], "%s%s%s%s%d%s", iconpath, "twotone_bluetooth_", color, "_", dpi, "dp.png");
	sprintf(bt_icons[1], "%s%s%s%s%d%s", iconpath, "twotone_bluetooth_disabled_", color, "_", dpi, "dp.png");

	sprintf(bar_icons[0], "%s%s%s%s%d%s", iconpath, "volume_bar_", color, "_", dpi, "dp.png");
	sprintf(bar_icons[1], "%s%s%s%s%d%s", iconpath, "brightness_bar_", color, "_", dpi, "dp.png");
	sprintf(bar_icons[2], "%s%s%s%s%d%s", iconpath, "dot_", color, "_", dpi, "dp.png");

	sprintf(critical_battery_icon, "%s%s", iconpath, "alert-outline-red.png");
}

void setupFuelGauge()
{
	//fuel_gauge_handle = i2cOpen(1, 0x36, 0);
	//i2cWriteWordData(fuel_gauge_handle, 0x18, 0x1770);
	//i2cWriteWordData(fuel_gauge_handle, 0x45, 0x0177);
	//i2cWriteWordData(fuel_gauge_handle, 0xDB, 0x8000);

	fuel_gauge_handle = wiringPiI2CSetup(0x36);
	wiringPiI2CWriteReg16(fuel_gauge_handle, 0x18, 0x2710);
	wiringPiI2CWriteReg16(fuel_gauge_handle, 0x45, 0x0271);
	wiringPiI2CWriteReg16(fuel_gauge_handle, 0xDB, 0x8000);
}

void setupBatteryCharger()
{
	//battery_charger_handle = i2cOpen(1, 0x6a, 0);
	//i2cWriteByteData(battery_charger_handle, 0x04, 0x18); // set charge current
	//i2cWriteByteData(battery_charger_handle, 0x03, 0x30); // set min sys voltage
	//i2cWriteByteData(battery_charger_handle, 0x02, 0x7D); // enable battery read
	//i2cWriteByteData(battery_charger_handle, 0x07, 0x8D); // disable watchdog timer

	battery_charger_handle = wiringPiI2CSetup(0x6a);
	//wiringPiI2CWriteReg8(battery_charger_handle, 0x04, 0x18); // set charge current
	wiringPiI2CWriteReg8(battery_charger_handle, 0x03, 0x30); // set min sys voltage
	wiringPiI2CWriteReg8(battery_charger_handle, 0x02, 0x7D); // enable battery read
	wiringPiI2CWriteReg8(battery_charger_handle, 0x07, 0x8D); // disable watchdog timer
}

void setupAudio()
{
	snd_mixer_selem_id_t* sid;
	const char* card = "default";
	const char* selem_name = "PCM";

	snd_mixer_open(&handle, 0);
	snd_mixer_attach(handle, card);
	snd_mixer_selem_register(handle, NULL, NULL);
	snd_mixer_load(handle);

	snd_mixer_selem_id_alloca(&sid);
	snd_mixer_selem_id_set_index(sid, 0);
	snd_mixer_selem_id_set_name(sid, selem_name);

	elem = snd_mixer_find_selem(handle, sid);
}

void setupButtons()
{
	//wiringPiISR(7, INT_EDGE_BOTH, &gpioISR7);
	//wiringPiISR(8, INT_EDGE_BOTH, &gpioISR8);
	//wiringPiISR(9, INT_EDGE_BOTH, &gpioISR9);
	//wiringPiISR(10, INT_EDGE_BOTH, &gpioISR10);
	//gpioSetISRFunc(7, EITHER_EDGE, 0, &gpioISR);
	//gpioSetISRFunc(8, EITHER_EDGE, 0, &gpioISR);
	//gpioSetISRFunc(9, EITHER_EDGE, 0, &gpioISR);
	//gpioSetISRFunc(10, EITHER_EDGE, 0, &gpioISR);
}

//------------------------------------------------------------------------------

IMAGE_LAYER_T createImageLayer(char* fileName, int layer)
{
	IMAGE_LAYER_T image;

	// Load image from path
	if (loadPng(&(image.image), fileName) == false)
	{
		fprintf(stderr, "unable to load %s\n", fileName);
		exit(EXIT_FAILURE);
	}

	createResourceImageLayer(&image, layer);

	return image;
}

void addImage(IMAGE_LAYER_T* img, int x, int y)
{
	update = vc_dispmanx_update_start(displayNumber);
	assert(update != 0);

	addElementImageLayerOffset(img, x, y, display, update);

	int result = vc_dispmanx_update_submit_sync(update);
	assert(result == 0);
}

void removeImage(IMAGE_LAYER_T* img)
{
	if (img->element == 0)
		return;

	update = vc_dispmanx_update_start(displayNumber);
	assert(update != 0);

	int result = vc_dispmanx_element_remove(update, img->element);
	assert(result == 0);

	result = vc_dispmanx_update_submit_sync(update);
	assert(result == 0);
}

void moveImage(IMAGE_LAYER_T* img, int x, int y)
{
	update = vc_dispmanx_update_start(displayNumber);
	assert(update != 0);

	moveImageLayer(img, x, y, update);

	int result = vc_dispmanx_update_submit_sync(update);
	assert(result == 0);
}

//------------------------------------------------------------------------------

double getBatteryVoltage()
{
	//int batteryVolt = i2cReadByteData(battery_charger_handle, 0x0E);
	int batteryVolt = wiringPiI2CReadReg8(battery_charger_handle, 0x0E);
	double voltage = ((batteryVolt >> 6) & 1) * 1280;
	voltage += ((batteryVolt >> 5) & 1) * 640;
	voltage += ((batteryVolt >> 4) & 1) * 320;
	voltage += ((batteryVolt >> 3) & 1) * 160;
	voltage += ((batteryVolt >> 2) & 1) * 80;
	voltage += ((batteryVolt >> 1) & 1) * 40;
	voltage += (batteryVolt & 1) * 20 + 2304;
	voltage /= 1000;
	if(voltage <= 0)
		return 3.0;
	return voltage;
}

int getChargingStatus()
{
	//int status = i2cReadByteData(battery_charger_handle, 0x0B);
	int status = wiringPiI2CReadReg8(battery_charger_handle, 0x0B);
	int charging = ((status >> 3) & 3);
	if (charging == 0)
		return 0; // discharging;
	else
		return 1; // charging
}

int getBatteryIndex(int percent)
{
	int status = getChargingStatus();

	if(status == 0)
	{
		for(int i = 0; i < 9; i++)
		{
			if (percent <= percent_levels[i])
				return i;
		}
	}
	return 9;
}

int getBatteryPercent()
{
	//uint16_t percent = i2cReadWordData(fuel_gauge_handle, 0x06);
	uint16_t percent = wiringPiI2CReadReg16(fuel_gauge_handle, 0x06);
	return percent >> 8;
}

void displayBattery(uint32_t tick)
{
	int status = getChargingStatus();
	int percent = getBatteryPercent();
	int index = getBatteryIndex(percent);

	if (critical_shutdown == 0 && percent < pmin && status == 0)
	{
		//addImage(&critical_battery_img,
		//	 (info.width - critical_battery_img.image.width) / 2,
		//	 (info.height - critical_battery_img.image.height) / 2);
		//critical_shutdown = 1;
		//critical_shutdown_tick = tick;
	}

	if (index != battery_index)
	{
		//addImage(&battery_img[index], info.width - battery_img[index].image.width, 0);
		//removeImage(&battery_img[battery_index]);
		battery_index = index;
	}
}

//-------------------------------------------------------------------------

int getVolumeLevel()
{
	long volume = 0;
	snd_mixer_selem_get_playback_volume(elem, SND_MIXER_SCHN_FRONT_LEFT, &volume);
	return volume;
}

void setVolumeLevel(int volume)
{
	snd_mixer_selem_set_playback_volume_all(elem, volume);
}

int getBrightnessLevel()
{
	char buf[4];
	FILE* fptr = fopen(backlight, "r");

	fgets(buf, 4, fptr);
	int brightness = atoi(buf);

	fclose(fptr);

	return brightness;
}

void setBrightnessLevel(int brightness)
{
	FILE* fptr = fopen(backlight, "w");

	fprintf(fptr, "%i", brightness);
	fclose(fptr);
}


void hideBar()
{
	if(display_volume == 1)
	{
		removeImage(&volume_bar_img);
		removeImage(&dot_img);
	}
	else if(display_brightness == 1)
	{
		removeImage(&brightness_bar_img);
		removeImage(&dot_img);
	}
	display_volume = 0;
	display_brightness = 0;
}

void displayVolumeBar(int volume)
{
	double dpi_d = dpi;
	int dotx = volume / 256.0 * (4.0 * dpi_d - dpi_d / 3.0) + dpi_d;

	if(display_volume == 1)
	{
		moveImage(&dot_img, dotx, 0);
	}
	else
	{
		if(display_brightness == 1)
		{
			removeImage(&brightness_bar_img);
			removeImage(&dot_img);
			display_brightness = 0;
		}
		addImage(&dot_img, dotx, 0);
		addImage(&volume_bar_img, 0, 0);
	}
	display_volume = 1;
	//display_tick = gpioTick();
	display_tick = micros();
}

void displayBrightnessBar(int brightness)
{
	double dpi_d = dpi;
	int dotx = brightness / 200.0 * (4.0 * dpi_d - dpi_d / 3.0) + dpi_d;

	if(display_brightness == 1)
	{
		moveImage(&dot_img, dotx, 0);
	}
	else
	{
		if(display_volume == 1)
		{
			removeImage(&volume_bar_img);
			removeImage(&dot_img);
			display_volume = 0;
		}
		addImage(&dot_img, dotx, 0);
		addImage(&brightness_bar_img, 0, 0);
	}
	display_brightness = 1;
	//display_tick = gpioTick();
	display_tick = micros();
}

//-------------------------------------------------------------------------

int getWifiLevel()
{
	FILE *fp = popen("iwconfig wlan0 | grep -i -w signal", "r");
	if (fp == NULL)
	{
		printf("failed to run command");
		exit(1);
	}

	char strength_str[6];
	char path[1000];
	int strength = 0;
	while (fgets(path, sizeof(path), fp) != NULL) {
		int index1 = rindex(path, '=') + 1 - path;
		int index2 = rindex(path, 'd') - path;
		memcpy(strength_str, &path[index1], index2 - index1);
	}
	pclose(fp);

	strength = atoi(strength_str);

	if (strength > -50)
		return 5;
	else if (strength > -65)
		return 4;
	else if (strength > -70)
		return 3;
	else if (strength > -80)
		return 2;
	else
		return 1;
}

void displayWifi()
{
	int index = -1;

	char buf[2];
	FILE* fptr = fopen(wifi_carrier, "r");
	fgets(buf, 2, fptr);
	fclose(fptr);

	int carrier_state = atoi(buf);
	if (carrier_state == 1)
	{
		index = getWifiLevel();
	}
	else
	{
		fptr = fopen(wifi_linkmode, "r");
		fgets(buf, 2, fptr);
		fclose(fptr);

		int linkmode = atoi(buf);
		if (linkmode == 1)
			index = 0;
	}

	if (index != wifi_index)
	{
		if (wifi_index != -1)
			removeImage(&wifi_img[wifi_index]);
		if (index != -1)
			addImage(&wifi_img[index], info.width - wifi_img[index].image.width - dpi, 0);

		wifi_index = index;
	}
}

//-------------------------------------------------------------------------

void displayBluetooth()
{

}

//-------------------------------------------------------------------------

int getCPUTemp()
{
	FILE *fp = popen(temp_cmd, "r");
	if (fp == NULL)
	{
		printf("failed to run command");
		exit(1);
	}

	char temp_str[6];
	char path[1000];
	while (fgets(path, sizeof(path), fp) != NULL) 
	{
		int index1 = rindex(path, '=') + 1 - path;
		int index2 = rindex(path, '\'') - path;
		memcpy(temp_str, &path[index1], index2 - index1);
	}
	pclose(fp);

	return atoi(temp_str);
}

void displayEnvironment()
{
	FILE *fp = popen(env_cmd, "r");
	if (fp == NULL)
	{
		printf("failed to run command");
		exit(1);
	}

	char env_str[6];
	char path[1000];
	while (fgets(path, sizeof(path), fp) != NULL) 
	{
		int index1 = rindex(path, 'x') + 1 - path;
		memcpy(env_str, &path[index1], 2);
	}
	pclose(fp);

	int env = atoi(env_str);
	int under_voltage_temp = env & 0x01;
	int freq_capped_temp = env & 0x02;
	int throttled_temp = env & 0x04;

	if (under_voltage != under_voltage_temp)
	{
		under_voltage = under_voltage_temp;
		if (under_voltage > 0)
			addImage(&under_voltage_img, info.width - under_voltage_img.image.width - dpi * 3, 0);
		else
			removeImage(&under_voltage_img);
	}

	if (freq_capped != freq_capped_temp)
	{
		freq_capped = freq_capped_temp;
		if (freq_capped > 0)
			addImage(&freq_capped_img, info.width - freq_capped_img.image.width - dpi * 4, 0);
		else
			removeImage(&freq_capped_img);
	}

	if (throttled != throttled_temp)
	{
		throttled = throttled_temp;
		if (throttled > 0)
			addImage(&throttled_img, info.width - throttled_img.image.width - dpi * 5, 0);
		else
			removeImage(&throttled_img);
	}
}

//-------------------------------------------------------------------------

void increase()
{
	if (misc_pressed == 1)
	{
		misc_alt = 1;
		int brightness = getBrightnessLevel();
		brightness = brightness + 10;
		if (brightness > 200)
			brightness = 200;
		setBrightnessLevel(brightness);
		//displayBrightnessBar(brightness);
	}
	else
	{
		int volume = getVolumeLevel();
		volume = volume + 5;
		if(volume > 255)
			volume = 255;
		setVolumeLevel(volume);
		//displayVolumeBar(volume);
	}
}

void decrease()
{
	if (misc_pressed == 1)
	{
		misc_alt = 1;
		int brightness = getBrightnessLevel();
		brightness = brightness - 10;
		if (brightness < 0)
			brightness = 0;
		setBrightnessLevel(brightness);
		//displayBrightnessBar(brightness);
	}
	else
	{
		int volume = getVolumeLevel();
		volume = volume - 5;
		if(volume < 0)
			volume = 0;
		setVolumeLevel(volume);
		//displayVolumeBar(volume);
	}
}

void restart_cmd()
{
	FILE *fp = popen("sudo /usr/local/bin/multi_switch.sh --es-pid", "r");
	if (fp == NULL)
	{
		printf("failed to run command");
		exit(1);
	}

	int pidRunning = 1;
	char path[1000];
	while (fgets(path, sizeof(path), fp) != NULL) {
		pidRunning = atoi(path);
	}
	pclose(fp);

	if(pidRunning == 0)
		system("sudo reboot");
	else
		system("sudo /usr/local/bin/multi_switch.sh --es-reboot");
}

void shutdown_cmd()
{
	//int status = i2cReadByteData(battery_charger_handle, 0x0B);
	//int status = wiringPiI2CReadReg8(battery_charger_handle, 0x0B);
	//status = status >> 5;
	//if (status == 0)
	//	wiringPiI2CWriteReg8(battery_charger_handle, 0x09, 0x6c); // shut down power to system
		//i2cWriteByteData(battery_charger_handle, 0x09, 0x6c); // shut down power to system

	FILE *fp = popen("sudo /usr/local/bin/multi_switch.sh --es-pid", "r");
	if (fp == NULL)
	{
		printf("failed to run command");
		exit(1);
	}

	int pidRunning = 1;
	char path[1000];
	while (fgets(path, sizeof(path), fp) != NULL) {
		pidRunning = atoi(path);
	}
	pclose(fp);

	if(pidRunning == 0)
		system("sudo shutdown -h now");
	else
		system("sudo /usr/local/bin/multi_switch.sh --es-poweroff");
}

void gpioISR7()
{
	uint32_t tick = micros();
	uint32_t tick_diff = 0;
	if (power_pressed == 0)
	{
		power_pressed = 1;
		power_tick = tick;
	}
	else
	{
		power_pressed = 0;
		tick_diff = tick - power_tick;
		if(tick_diff < powerButtonTime)
		{
			run = false;
			restart = true;
		}
	}
}

void gpioISR8()
{
	uint32_t tick = micros();
	if(misc_pressed == 0)
	{
		misc_pressed = 1;
		misc_tick = tick;
	}
	else
	{
		misc_pressed = 0;
		misc_alt = 0;
		misc_tick = 0;
	}
}

void gpioISR9()
{
	uint32_t tick = micros();
	if(increase_pressed == 0)
	{
		increase_pressed = 1;
		increase_tick = tick;
		increase();
	}
	else
	{
		increase_pressed = 0;
		increase_tick = 0;
	}
}
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
int main(int argc, char *argv[])
{
	//gpioInitialise();

	int result = 0;
	int cpuTemp = 0;
	int sleepMilliseconds = 100;
	uint32_t tick = 0;
	uint32_t previousTick = 0;
	uint32_t tickDiff = 0;
	int fanTick = 0;
	int fanState = 0;

	wiringPiSetupGpio();

	setupFiles();
	setupFuelGauge();
	setupBatteryCharger();
	//setupDisplay();
	setupAudio();
	setupButtons();

	//loadInitialImages();

	previousTick = micros();
	tick = previousTick;

	while(run)
	{
		cpuTemp = getCPUTemp();
		tick = micros();
		tickDiff = tick - previousTick;
		if (tickDiff > 1000000)
		{
			previousTick = tick;
			displayBattery(tick);
			//displayWifi();
			//displayEnvironment();

			if (fanTick > 0)
				fanTick = fanTick - tickDiff;
		}

		// check volume bar and hide if out for more then 3 seconds
		//if ((display_volume == 1 || display_brightness == 1) && tick - display_tick >= volbriBarTime)
			//hideBar();

		// check to see if the misc button has been held down but not being used for alternate increase and decrease buttons
		if (misc_pressed == 1 && misc_alt == 0 && tick - misc_tick >= miscButtonTime)
		{
			system("sudo ifconfig wlan0 down");
			system("sudo ifconfig wlan0 up");
			misc_pressed = 0;
			misc_tick = 0;
		}

		// check if the power button is held down for the power off
		if (power_pressed == 1 && tick - power_tick >= powerButtonTime)
		{
			power_pressed = 0;
			shutdown = true;
			//printf("test");
			break;
		}

		// check to see if the increase is held down
		if (increase_pressed == 1 && tick - increase_tick >= incdecButtonTime)
		{
			display_tick = tick;
			increase();
		}

		// check to see if the decrease is held down
		if (decrease_pressed == 1 && tick - decrease_tick >= incdecButtonTime)
		{
			display_tick = tick;
			decrease();
		}

		// check to see if the critical shutdown is going
		if (critical_shutdown == 1 && tick - critical_shutdown_tick >= criticalShutdownTime)
		{
			critical_shutdown = 0;
			shutdown = true;
			break;
		}

		// turn on fan if the cpuTemp is above the fan limit
		if (cpuTemp > fan_on_temp)
			fanTick = fanMinTime;

		if (fanState == 0 && fanTick > 0)
		{
			digitalWrite(12, 1);
			fanState = 1;
		}
		else if (fanState == 1 && fanTick <= 0)
		{
			digitalWrite(12, 0);
			fanState = 0;
		}

		updateGPIO();

		usleep(sleepMilliseconds * 1000);
	}


	//destroyImageLayer(&critical_battery_img);
	//for (int i = 0; i < 10; i++)
		//destroyImageLayer(&battery_img[i]);
	//destroyImageLayer(&volume_bar_img);
	//destroyImageLayer(&brightness_bar_img);
	//destroyImageLayer(&dot_img);

	//result = vc_dispmanx_display_close(display);
	//assert(result == 0);


 	snd_mixer_close(handle);

	if (shutdown == true)
		shutdown_cmd();
	else if (restart == true)
		restart_cmd();

	//printf("test");

	//gpioTerminate();
	return 0;
}

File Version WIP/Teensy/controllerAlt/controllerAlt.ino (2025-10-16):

#include <XInput.h>

uint8_t smallRumbleCounter = 0;
uint8_t bigRumbleCounter = 0;

// Define button pins
uint8_t inputButtonCount = 16;
uint8_t inputButtonPins[16] = {1, 2, 3, 4, 5, 6, 7, 8, 9, 10, 11, 12, 16, 17, 18, 19};
uint8_t outputButtonCount = 2;
uint8_t outputButtonPins[2] = {22, 23};

int deadZone = 125;
int serialCount = 0;

// Setup the debouncing

void setup() {  
  Serial1.setRX(25);
  Serial1.setTX(24);
  Serial1.begin(38400);

  for(int i = 0; i < inputButtonCount; i++) {
    pinMode(inputButtonPins[i], INPUT_PULLUP);
  }

  for(int i = 0; i < outputButtonCount; i++) {
    pinMode(outputButtonPins[i], OUTPUT);
    analogWriteFrequency(outputButtonPins[i], 187500);
  }

  XInput.begin();

  XInput.setTriggerRange(0, 1);
  XInput.setJoystickRange(200, 800);
}


void loop() {
  boolean upPad = !digitalRead(5);
  boolean downPad = !digitalRead(3);
  boolean leftPad = !digitalRead(2);
  boolean rightPad = !digitalRead(6);

  boolean buttonA = !digitalRead(11);
  boolean buttonB = !digitalRead(10);
  boolean buttonX = !digitalRead(17);
  boolean buttonY = !digitalRead(16);
  boolean buttonLB = !digitalRead(8);
  boolean buttonRB = !digitalRead(18);
  boolean buttonL3 = !digitalRead(4);
  boolean buttonR3 = !digitalRead(12);
  boolean buttonStart = !digitalRead(9);
  boolean buttonSelect = !digitalRead(1);

  int buttonLT = !digitalRead(7);
  int buttonRT = !digitalRead(19);

  int leftStickX = analogRead(1);
  int leftStickY = analogRead(0);

  int rightStickX = 1000 - analogRead(7) + 125;
  int rightStickY = 1000 - analogRead(6);

  uint8_t bigRumble = XInput.getRumbleLeft();
  uint8_t smallRumble = XInput.getRumbleRight();
  uint8_t bigRumbleSet = 0;
  uint8_t smallRumbleSet = 0;

  if ((leftStickX > (500 - deadZone)) && (leftStickX < (500 + deadZone)))
    leftStickX = 500;
  if ((leftStickY > (500 - deadZone)) && (leftStickY < (500 + deadZone)))
    leftStickY = 500;

  if ((rightStickX > (500 - deadZone)) && (rightStickX < (500 + deadZone)))
    rightStickX = 500;
  if ((rightStickY > (500 - deadZone)) && (rightStickY < (500 + deadZone)))
    rightStickY = 500;

  XInput.setDpad(upPad, downPad, leftPad, rightPad);
  XInput.setJoystickY(JOY_LEFT, leftStickY, true);
  XInput.setJoystickX(JOY_LEFT, leftStickX);
  XInput.setJoystickY(JOY_RIGHT, rightStickY, true);
  XInput.setJoystickX(JOY_RIGHT, rightStickX);

  XInput.setTrigger(TRIGGER_LEFT, buttonLT);
  XInput.setTrigger(TRIGGER_RIGHT, buttonRT);
    
  XInput.setButton(BUTTON_A, buttonA);
  XInput.setButton(BUTTON_B, buttonB);
  XInput.setButton(BUTTON_X, buttonX);
  XInput.setButton(BUTTON_Y, buttonY);
  XInput.setButton(BUTTON_LB, buttonLB);
  XInput.setButton(BUTTON_RB, buttonRB);
  XInput.setButton(BUTTON_L3, buttonL3);
  XInput.setButton(BUTTON_R3, buttonR3);
  XInput.setButton(BUTTON_START, buttonStart);
  XInput.setButton(BUTTON_BACK, buttonSelect);

  // Lower the rumble values for the motors in the handheld
  if (bigRumble > 25)
  {
    bigRumbleCounter = 0;
    bigRumbleSet = bigRumble / 8 + 45;
  }
  else
  {
    if (bigRumbleCounter > 10)
      bigRumbleSet = 0;
    else
      bigRumbleCounter = bigRumbleCounter + 1;
  }

  if (smallRumble > 25)
  {
    smallRumbleCounter = 0;
    smallRumbleSet = smallRumble / 8 + 45;
  }
  else
  {
    if (smallRumbleCounter > 10)
      smallRumbleSet = 0;
    else
      smallRumbleCounter = smallRumbleCounter + 1;
  }

  analogWrite(23, bigRumbleSet);
  analogWrite(22, smallRumbleSet);

  /*
  serialCount = serialCount + 1;
  if (serialCount > 20)
  {
    serialCount = 0;
    Serial1.print("Left_X: ");
    Serial1.print(leftStickX);
    Serial1.print(", ");
    Serial1.print("Left_Y: ");
    Serial1.print(leftStickY);
    Serial1.print(", ");
    Serial1.print("Right_X: ");
    Serial1.print(rightStickX);  
    Serial1.print(", ");
    Serial1.print("Right_Y: ");
    Serial1.print(rightStickY);
    Serial1.println();
  }
  */
  
  delay(50);
}

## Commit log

2022-07-19 Adding initial files. Still WIP
    [Aegis PCB MB v95.brd, Aegis_PCB_MB_v46.sch, Back Center.stl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]
2022-07-28 Adding updated circuit boards and gerber files
    [Aegis PCB - 1 v113.brd, Aegis PCB - 1 v58.sch, Aegis PCB - 2 v35.sch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]
2023-05-09 Updated the CAD files and provided a BOM
    [Aegis 2 BOM.xlsx, Aegis PCB - 1 v113.brd, Aegis PCB - 1 v58.sch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]
2023-05-09 Updated the battery on the BOM to the correct one
    [Aegis 2 BOM.xlsx]
2023-05-09 Adding the Panel Driver for the screen for Bullseye Updating the monitor.c file so that the buttons work with the KMS driver even though the display still does not Added the WiringPi folder in case t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
    [monitor.c]
2023-05-10 Adding internal supports for the back center case piece
    [Back Center.stl]
2025-10-16 feat: adding new files I never got around to adding.
    [Aegis 2 BOM.xlsx, Back With Grips.3mf, Front Outer Alt.stl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]
2025-10-16 feat: adding images and alternate circuit board
2025-12-13 feat: added updated BOM, new controller code for better button debouncing and a version of the controller code that supports calibration for the joysticks.
2025-12-13 feat: added the clear acrylic sheet to the BOM for the front of the screen
